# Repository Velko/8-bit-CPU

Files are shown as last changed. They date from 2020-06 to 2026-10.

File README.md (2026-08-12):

8-bit-CPU
=========

After watching [series of videos][eater-net-8bit] by Ben Eater building an 8-bit computer from scratch,
I was hooked. Various thoughts for improvements and experiments was running through my mind. But first
I have to build one. Improvements will come later. Whom am I kidding? I'll never be able to build an
exact replica, I'll incorporate improvements as I go.

In contrast to Ben, I'm not that crazy about building the whole thing on breadboards. PCBs are fine,
I like them, but building the whole thing on single board takes away the flexibility. So the plan is
to make a small board for each module and connect them together.

I plan to build a prototype module on breadboard, play around with it and then design and make a PCB
for it. It might also be interesting to make the boards little customizable (leave a chip out, create
a solder bridge, use shorter connector) so that they can be re-used for different purposes.

Of course, some parts of it might stay on a breadboard forever, or I might choose to create PCBs for
those as well. I don't know, time will tell. But the main idea is that it should be possible to swap
out PCBs for breadboards and vice versa.

Key differences from Ben's version
==================================

256 bytes of memory
-------------------

I felt that 16 bytes of total memory might be too tight, went for 8-bit addressing and 256 bytes
of memory straight from the beginning. "Real" 32 KiB SRAM chip is used, with remaining higher address
lines tied to ground. Expanding to 256 bytes does not introduce more complexity, I think that it even
made things easier. The emulated version has (and is able to use) 64KiB of memory, hardware version
has not catched up with it yet.

ROM and bootloader mode
-----------------------

I was not in the mood for _any_ DIP switch toggling for program entry, so I added an EEPROM instead.
Still I did not want to go full Harvard architecture with separate program and data memories, so
there's bootloader mode instead.

To enable it, RAM's Chip Enable is connected together with Write Enable, while ROM's Chip Enable is
connected with Output Enable of the RAM. What happens is that all reads comes from ROM and all writes
goes into RAM.

I have bootloader code in the beginning of the program that copies contents of all 256 bytes into RAM
and then patches itself (in RAM) to be skipped. It is nice to have more memory, since in original
version there are only 16 bytes total, but I can afford to _waste_ similar amount on bootloader.

In _run mode_ ROM's Chip Enable is tied to disabled state permanently, while RAM is permanently enabled.

4 flags
-------

In addition to Z and C flags, there are Negative and oVerflow flags. Took an inspiration from
[AVR Instruction Set Manual][avr-instructions], on how to implement various branching instructions.
N and V flags are required for some. N bit is just a copy of 7-th bit of the result. oVerflow indicates
that the sign bit "overflowed" as a result of addition/subtraction. In short it can be defined as:
*If sign bits of both addition operands are equal, but sign bit of the result is different, the overflow
occured.*

C flag got an additional update to act as a Borrow bit in subtraction. It behaves same way as in
Z80 / AVR / x86 processors. In subtraction the meaning of C is opposite from 6502 or Ben's version,
I find this more intuitive.

256 opcodes
-----------

As memory was expanded to 256 bytes, it was not possible to encode opcode and address in single byte
anymore. Instructions may require multiple bytes anyway now. Instruction Register loads 8-bit opcode and
extra arguments are fetched from RAM when needed, there's room for 256 opcodes.

However, number of opcodes is also limited by capacity of control EEPROMs. 8 bits for opcode + 4 bits
for flags + 3 bits for instruction step = 15 address lines. This calls for 32K EEPROM - 28C256. They
felt a little pricey when I ordered parts and I was not completely sure if I'll really need them. For
now I only have 28C64 chips, limiting number of opcodes to 64. It is still 4 times more than in Ben's
version.

There are plans to support "extended" opcodes (up to 512, or even more, if required). Planning to switch
to SST39SF010A chips for microcode ROMs. These have more capacity (and address lines) and are a bit
cheaper as well.

Modular ALU
-----------

Currently there are 2 ALU modules: Add/Subtract (with or without carry/borrow),
and AND/OR. 2 more modules are about to come - XOR/NOT, Shift/Nibble-swap.

Flags register as an independent entity
---------------------------------------

Zero flag's calculation takes input from the Bus, instead of being embedded in ALU module. This allows
to add additional ALU modules and keep just one instance of Z calculation circuitry. Additionally, it
is possible to calculate flags for anything on the Bus, for example - while loading byte from memory.
There's additional function for flags register to be sent and loaded from bus directly. Currently
there is no use for that, but it may become handy if flags need to be saved and restored for some reason
(perhaps, to implement interrupts).

Double-latching registers
-------------------------

One of the main sources of instability in Ben's design is that registers' "tap outputs" (ones that
connects registers to ALU, RAM or Control Logic) change immediately when new value is latched.
This is especially important with Flags and Instruction Register, as it creates the infamous
"EEPROM noise" on the rising clock edge, when it can cause unexpected effects. It might not be such
an issue for general-purpose registers or MAR, but it is better that everything holds steady while
the clock line is high.

The double-latching technique adds additional D flip-flops between register's primary ones and its
"tap output". These additional flip-flops are configured to latch on the inverted clock, therefore
output stays unchanged until the falling edge.

Dual-output registers
---------------------

General purpose registers got dual 3-state "tap outputs". Instead of ALU inputs being hardwired to
registers A and B, now (with appropriate control signals) it is possible to connect them differently,
for example do A + A directly. It also allows additional registers (C and D), that could be used
with ALU directly. Currently this feature is not used and control lines are wired for steady "on",
but the potential is there.

Quarter-clock
-------------

One of the sources of instability in Ben's version is RC-circuit used as an edge detector in RAM
module. A common technique is to isolate the circuit using extra logic gates, so that it does not
send spikes back in clock line. I, however, decided to eliminate the need for edge detection
completely. The thing with RAM is that it will keep loading the value all the time while Write Enable
line is enabled. If inputs change, the last value will be stored, which may not be one we want if
Write Enable is disabled on same moment as other control lines starts to change. Ben solved it using
edge detector circuit, I went in another direction and introduced a "dead time" between moment when
primary clock line goes low and inverted clock rises.

Added a counter (could have been anything that can divide the frequency) and few NOR gates on the
*clock module* I generate two 25% duty-cycle clock signals, that are offset by half of the cycle. It
looks like this:

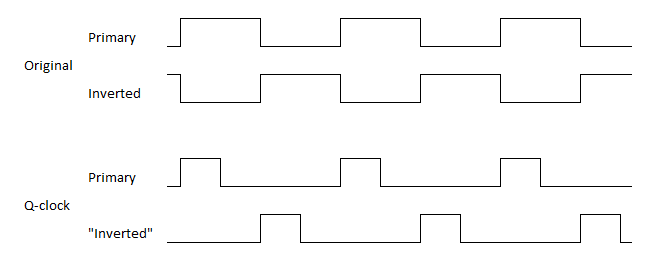
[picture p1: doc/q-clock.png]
q-clock


Part of the cycle when both clocks are low ensures that RAM's Write Enable is not active when control
lines or bus changes.

While it is required only by RAM module, I see no downsides for using it globally (it might be an issue
at high clock frequencies, though). Also, now other un-clocked parts (e.g. 193 counter for Stack Pointer)
can be introduced without worries.

Muxed control lines
-------------------

A great way to save bits in Control EEPROMs is to add demultiplexers, which activates just a single line
from several. For example, by using 74*138 demultiplexer one can expand 3 bits to 7 control lines
(technically - to 8, but you need to reserve one as "unused"). Currently there are 2 demultiplexers
used - for OUT and for LOAD lines. For OUT it also prevents "invalid" conditions, such as multiple
modules trying to output value on the bus.

While, in theory, there might be need to load same value into multiple modules simultaneously, I've
not yet encountered one, and I'm happy to live with that limitation.

No MAR, separate Address Bus
----------------------------

While trying to adjust the architecture for 16-bit memory space, I found out that having a single
Main Bus and Memory Address Register comes with performance penalty, as all address transfers takes
more cycles.

After some experimentation I found out that the most optimal solution is to remove the MAR entirely
and have a separate 16-bit Address Bus, connected directly to the RAM chip(s).

Now, for example, Progam Counter can put an address on this bus, and the data is available to be sent on the
Main Bus.

Additionally, I re-designed PC in a way, that it can output the "old" value on the Address Bus, and
increment itself simultaneously. As a result, I can reduce the fetch stage of each instruction to just
single cycle.

There are some situations (like JMP instruction), when data should be exchanged between Address and
Main buses. There's a pair of special Transfer Registers, that allows to transfer low or high bytes
between the buses.

Arduino + Python test module
----------------------------

It started with hooking up an Arduino (on its own at first, then expanded output with 595 shift registers,
expanded even more with 139 demultiplexers and finally added 165 for expanded input) and writing some
sketches to verify if modules work as expected. Soon I realized that the environment is a bit limited
and while it can prove that everything works, it is not very helpful for diagnostics.

Reducing the functions of Arduino to "set control lines", "put to bus", "read from bus", "read flags",
"pulse a clock", etc. and implementing higher level logic in Python, makes it more flexible and quicker
to develop. Wrote a "client" that uses interactive input for diagnostics.

Started to implement Python functions that acts as an assembly instructions - for example: add(A, B)
switches all control lines and issues clock ticks as needed for the addition operation. Basically -
implemented microcode in Python. Later, with refactoring it became my main microcode definition and
is used as primary source for microcode EEPROM contents.

Using the instruction-like functions and [pytest][pytest] framework wrote a quite thorough test suite.
It can check couple hundred scenarios in just few seconds and point out if something does not work as
expected. It has already saved me several times, when I did some rewiring.

At the moment the test module is swapped out for "real" EEPROM-based Control Logic, but I'll definitely
find a way to use both of them in parallel, as it is too useful to be retired.

Programmed using CustomAsm
--------------------------

There was Python-based "assembler" at first, but in the end I adopted [CustomAsm][customasm] for
machine code generation. There's an utility that takes my microcode definition and exports a file,
describing them for [CustomAsm][customasm]. It takes it from there.

Debugger & IDE
--------------
As the Test module allows great deal of flexibility, I was able to also develop a simple debugger.
It can examine registers, RAM contents, single step. Addition of BRK instruction and corresponding
control line introduced ability to set breakpoints and run the program in full-speed. Unfortunately
it only works with emulator, as current hardware doesn't support both "normal" Control Logic and
Test modules connected simultaneously.

Later I went even further and developed a simple IDE, that allows basic code editing, integrates
with [CustomAsm][customasm] for compilation and has basic debugging functionality. One can single-step,
set breakpoints, examine registers. The IDE is far from polished experience, still it is useful.

Side-projects: EEPROM and Flash writers
---------------------------------------

As side projects, there are 2 boards (Arduino Uno shields), firmware and client utility for
programming DIP-28 and PLCC-32 EEPROMs (AT28C64 and AT28C256), as well as PLCC-32 Multi-Purpose
Flash (SST39SF*).

EEPROM board has additional headers, giving access to address and data pins, allowing the board to
act as a Test module, when connected to the Main Bus and control lines.

File upload and download uses XMODEM protocol, can be used with any terminal emulator. There's also
a (*nix-only) command-line client utility for convenience.

Emulated in Verilog
-------------------

In order to be able to work with the software side of the project, when hardware was not available,
I wrote an in-Arduino emulator, that speaks same protocol as Test module. With time that proved to
be insufficient, as Arduino was still needed, so I ported the C++ code to run on PC. It worked fine,
but was a hand-crafted approximation of the CPU, so I could not really test all "what if" scenarios
I'd like to.

So I decided to build another emulator, using proper hardware description language - [Verilog][verilog].
The idea was that I first make "building blocks" - (hopefully accurate) implementations of 74-series
logic chips, and then connect them together into CPU modules. This way I get a runnable representation
of the thing, how it should be built with real chips.

To provide connectivity with (virtualized) serial port, I built additional [VPI][vpi] module.

Repository index
================

* **.github** - configuration files for GitHub integration, e.g. workflows for GitHub Actions
* **.vscode** - configuration for Visual Studio Code
* **arduino** - Arduino sketches and C++ code, to help test and automate things
    * **bouncyy** - software button debouncer and "rebouncer"
    * **pincontrol** - substitute Control Logic. Controlled via serial link from **pycontrol**
    * **xmprog** - EEPROM/Flash programmer, file upload using XMODEM protocol
* **demo** - demo programs
* **doc** - some (mostly outdated) design thoughts, BOM, etc.
* **emulator** - hardware emulator in Verilog
    * **chips** - Verilog descriptions of (mostly 74xx) chips
    * **cpu-modules** - "wired up" CPU modules
    * **tests** - test benches for chips and modules
    * **vm** - a "virtual machine". Speaks same protocol as **pincontrol**
* **hardware** - hardware schematics, boards, etc.
    * **breadboard** - Fritzig projects for some modules
    * **pcb** - KiCad schematics and boards
        * **alu_back** - backplane board for ALU and GP registers
        * **aunit** - Arithmetic Unit (ALU module for addition and subtraction)
        * **clock** - (unfinished) Clock module
        * **control** - (unfinished) Control Logic
        * **counter** - Program Counter
        * **display_back** - backend board for Output module (7-seg display)
        * **display_front** - frontend board for Output module (7-seg display)
        * **eeprom_burner** - EEPROM writer as Arduino Uno shield
        * **flags** - Flags register
        * **flash_writer** - Arduino Uno shield - writer for SST39SF0*-series Flash chips (chosen EEPROM replacement)
        * **keyboard** - (unfinished) 4x4 keyboard scanner module
        * **lunit** - Logic Unit (ALU module for AND and OR)
        * **modules** - Register, ALU, etc. boards as KiCad footprints (for backplane)
        * **ram** - (unfinished) RAM module
        * **register** - GP register
        * **sunit** - Shift Unit (ALU module for shift and nibble swap)
        * **transfer** - transfer register (between Main Bus and Address Bus)
* **include** - C and .def files for inclusion on other programs
* **misc** - miscellaneous utilities
    * **digits** - an utility to generate binary ROM image for 7-segment display
    * **xmclient** - PC-side client utility for **xmprog**
* **parts** - custom KiCad symbols and footprints for missing components
* **pycontrol** - Python-based control logic, microcode, tests, demo programs, etc.
    * **ide** - a simple PyGTK-based IDE with graphical debugger
    * **libcpu** - main implementation of control logic, microcode
    * **stubs** - MyPy type definitions for packages that lack those
    * **tests** - PyTest scripts, testing (real or emulated) hardware and PyControl itself
    * **tools** - various tools that generates microcode, customasm definitions, execute and debug binaries
* **simulation** - [Logisim][logisim] and [Digital][digital] simulations for tricky logic
* **turbo** - high-performance hardware emulator in Rust
    * **core** - core CPU implementation
    * **peripherals** - implementations of various peripherals, e.g. displays, UART, etc.
    * **bridge** - communication bridge between emulator and clients over UDP
    * **vm** - a "virtual machine", tying it all together

Progress
========

* Created Github project and added few most immediate tasks
* Wrote an introductionary README (this one ;-) )
* Decided on overall design
* Compiled list of modules and parts for first experiments, placed an order with my favorite supplier
* Found Arduino, breadboard and few 7-segment displays at home. Time to practice!
* Built breadboard prototypes for Clock, Register, Counter, Display and EEPROM burner
* Built ALU, complete with upgraded Flags register.
* Wrote some [blog posts][velkoraspi] about the "adventures"
* Arduino-based testing device. Connect the module, run a command and it verifies that module works
  as expected.
* Designed, soldered PCB versions of Register, ALU, Flags and EEPROM programmer
* Reworked testing device - moved most logic to "client" side. Coding in Python is a lot quicker
  than constantly re-flashing the Arduino. Can use unit-test framework, use debugger, quick edits.
* Beginnings of instruction set.
* Soldered 2 more Registers, to be used as MAR and IR
* Built breadboard prototype of RAM module (placed MAR and IR on it), wrote some unittests for it
* Wired both ALU and RAM blocks to Arduino, merged test suites
* Hey, it can calculate and there's memory. That should be enough to do something more complex.
* Developed Sieve of Eratosthenes - calculate prime numbers up to 256. A Python program, which uses
  assembly-like functions to manipulate the ALU and RAM modules. All variables/arrays required for
  algorithm are stored in the RAM. The control flow reads its input only from Flags register. This
  should be almost 1:1 translatable to assembly / machine code
* Play around with Python AST visitor to automatically "flatten" the program and add necessary labels
  and jumps to replace Python's while/if/continue/break control flow. When executed, this program generates
  machine code.
* Built a dedicated "debug control" board using Nano, shift registers and demultiplexers
* Connected Program Counter and "read-back" from IR into Arduino. Should be able to "run" programs from
  memory
* Developed a Python-side instruction interpreter, which uses input from IR and flags to select and
  execute appropriate microcode steps. Now it really runs machine code, albeit using weird (and very slow)
  control logic
* Developed utility that dumps current microcode (Python) definitions to C arrays.
* Wrote an Arduino-side instruction interpreter that uses the C microcode arrays and input from IR and
  Flags. Now can run programs without Python-side involvement
* Added an EEPROM in RAM module. Added a bootloader code in the Prime Sieve demo. The bootloader copies
  contents from ROM into RAM and patches itself to be skipped next time
* Implemented a "quarter clock" on the Clock board. Now it produces two 25% duty-cycle clock signals,
  instead of two 50% ones. This should eliminate need for edge-detection circuitry in RAM module.
* Built an EEPROM-based control board. Flashed microcode into ROMs.
* Swapped out Arduino-based control board with EEPROM-based one. A very error-prone operation, I must admit.
* IT'S ALIVE!!! The Sieve of Eratosthenes runs without involvement of any additional processor!
* I pushed it for speed. Initially there were some instability, but I noticed that connection of N flag
  from Flags to Control Logic was loose. Nothing in the code uses N flag for now, that's why it did not
  fail immediately. Once that was fixed, it appears to be rock-solid. I even pulled the capacitor from the
  astable clock, making it go as fast as it can. It's been running that way for over a week - not a single
  misstep.
* Some shooting, video editing and [announcement on Reddit][first-announce].
* Working on updated versions of boards, as there were design issues
* Improving reliability of Python code by adding type annotations
* Wrote emulators. Python-side instruction interpreter for quick code debugging and in-Arduino hardware
  emulator. These should help to move software side forward while there is no combined Arduino- and
  EEPROM-based control logic.
* Fixed/redesigned new versions for Arithmetic Unit and Flags boards. An experimental ALU backplane.
* Extended in-Arduino hardware emulator to 16-bit addressing. An easy way to check out various ideas
  before actually building the hardware.
* Adopted [CustomAsm][customasm] for machine code generation. Can retire my own Python-Assembly.
* Developed a debugger (breakpoints, single step, live register inspection).
* Designing additional ALU modules, miniaturized Display module.
* Ported hardware emulator to run on PC. Configured GitHub Actions to run tests.
* Designed boards for AND/OR unit, Display module, Program Counter, Transfer Register, Flash Writer
* Started re-trace branch. Software side and emulation has progressed quite far since first demo.
  On the hardware side, new boards are just starting to roll in, and I need microcode and programs
  to test the build. Can not really just follow the original version history path, because then I
  will not have access to latest software improvements. (CustomAsm, MyPy, etc.), Instead I took the
  "latest and greatest" and removed all features that are not supported by hardware yet. Will gradually
  add those back as I assemble the CPU.
* Replaced the hardware emulator with one developed in Verilog. Implemented 74-series chips as basic
  building blocks. The rest of the machine is "wired up" from those blocks. It gives a runnable version
  and represents how it can be built on breadboards or PCBs. Same as previous implementation, it can
  be controlled via virtual serial connection.
* Merged EEPROM burner, Flash writer and XMProg firmwares into one. Now it can program EEPROMs and Flash
  ROMs (should plug in the right Arduino shield) from binary file uploads over XMODEM protocol.
  Interestingly, something in Arduino library was interfering with serial communication, so everything
  was ported to C and depends on [AVR-Libc][avr-libc] only. The built-in functionality of content
  generation for 7-segment display and microcode ROMs were ported to separate utilities.
* Developed a simple IDE / GUI debugger. Probably I should've created a VSCode extension, but it I feel
  more comfortable in creating a whole app in PyGTK.
* Designing "universal" I/O controller, up to 64 (or 256) ports for external devices.
* Extracted the device pinout and instruction set definitions from Python code into separate yaml files.
  This way they can be used by an alternative implementations, for example - a high-performance emulator
  in C or Rust.
* Switched from virtual serial connection to UDP. It is more flexible and also allows to "hot-reconnect"
  with a different tool. It also appears that performance is better, especially when running in GitHub
  Actions. To use with an Arduino-based control board, I may try it using Socat or implement an
  UDP-to-Serial bridge myself, but I'll do that in due time.
* Implemented classic Snake game. It listens for input on UART and sends back ANSI-escaped output.
  Fixed a lot of issues and added new features to make it possible.
* Reimplemented the GUI debugger as TUI, using [Textual][textual] library. It is more convenient to
  run it in SSH session. No code editing nor compilation features, focused on debugger because it was
  fiddly to run the GTK version in remote session. It was quite hard to develop the Snake game demo
  without usable debugger UI. I had only a cmd-based one, which was not very convenient.
* Implemented another emulator, this time in Rust. This is a high-performance one, nicknamed "Turbo".
  It can be controlled using the same protocol as the Verilog-based emulator, so it can be used as a
  drop-in replacement. The performance difference is staggering - the Snake game does not have a chance
  to receive an input before the snake has ran into a wall. In Verilog emulator the game was playable,
  despite that it does not wait on any timers to slow down.

[eater-net-8bit]: https://eater.net/8bit
[velkoraspi]: https://velkoraspi.blogspot.com/
[avr-instructions]: http://ww1.microchip.com/downloads/en/devicedoc/atmel-0856-avr-instruction-set-manual.pdf
[pytest]: https://docs.pytest.org/en/stable/
[first-announce]: https://www.reddit.com/r/beneater/comments/loy9kj/important_milestone_it_works/
[customasm]: https://github.com/hlorenzi/customasm
[digital]: https://github.com/hneemann/Digital
[logisim]: http://www.cburch.com/logisim/
[verilog]: https://en.wikipedia.org/wiki/Verilog
[vpi]: https://en.wikipedia.org/wiki/Verilog_Procedural_Interface
[avr-libc]: https://www.nongnu.org/avr-libc/user-manual/index.html
[textual]: https://textual.textualize.io/

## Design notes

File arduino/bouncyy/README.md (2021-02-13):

Bouncyy
=======

A small tool for switch de-bounce and external debouncer testing. It takes an
input from switch, performs debouncing in software and outputs clean signal.

Also it generates another output, that is guaranteed to bounce few times.
This signal is intended to test if other (e.g. 555-based) debouncers are up
to the task. Mechanical switches are unpredictable and may or may not introduce
noticable bounces, but this tool will do.

It is implemented using "Arduino Femto" (bare ATtiny25 chip), but it should be
easily portable to larger Arduino boards.

Wiring
------

The device is a bare ATtiny25 chip, it requires only power and ground. Input
and output should be wired as follows:

* PB2 - switch input (active low, pull-up enabled)
* PB0 - debounced output (active high, debounced)
* PB1 - re-bounced output (active low, guaranteed bounce, copies button)

Programming
-----------

ATtiny should be wired to external programmer - it is required to connect MISO,
MOSI, SCK and RESET pins.

The Makefile is configured for [USBasp][usbasp] programmer, but it should be
possible to adapt it easily for other devices.

When fresh ATtiny is programmed, it is necessary to adjust its _fuse bits_, as
the default setting is to run it using internal 1 MHz clock. While it could have
been enough for this application, I prefer to switch the clock to 8 MHz mode. The
command for this is:

    make fuses

The firmware can be uploaded using command:

    make upload

[usbasp]: https://www.fischl.de/usbasp/

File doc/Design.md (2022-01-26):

Overall design
==============

The overall structure starts out same as used in breadboard computer built by Ben Eater. It has,
however, evolved quite a lot away from it.

+------------+  +------------+------------+
|     PC     |  | Register A |   Add/Sub  |
+------------+  +------------+------------+
|     LR     |  | Register B |   And/Or   |
+------------+  +------------+------------+
|     RAM    |  | Register C | Shift/Swap |
+------------+  +------------+------------+
|     TH     |  | Register D |   Xor/Not  |
+------------+  +------------+------------+
|     TL     |  |    Flags   |     ?      |
+------------+  +------------+------------+
|     SP     |
+------------+
|    ACalc   |
+------------+

+------------+
|     IR     |
+------------+

+------------+
|    OUT     |
+------------+

Each module eventually will be implemented as PCB. All modules should be plugged into a back-bone
PCB, that provides bus connectivity, power and control signals. Module PCBs should be designed in
a way that allows them to be plugged into breadboards.

Planned modules are:
* CLK          - clock
* Register A-D - general purpose registers
* Add/Sub      - ALU module for addition and subtraction
* And/Or       - ALU module for bitwise AND and OR
* Shift/Swap   - ALU module for bit shift and nibble-swap
* Xor/Not      - ALU module for bitwise XOR and negation
* Flags        - flags register
* PC           - program counter
* LR           - link (return address) register
* RAM          - memory
* TH/TL (TX)   - transfer register (between Main and Address buses)
* SP           - stack pointer
* ACalc        - address calculator (for relative addressing)
* OUT          - numeric output register
* IR           - instruction (decoder) register

* DSP   - display
* IN    - input device
* CTRL  - control unit
* BUSM  - bus monitor
* TEST  - Arduino-based test module

Registers
=========

General purpose registers A, B, C, and D should be able to load 8-bit value from the bus, output it
back and provide two 3-state "tap" outputs for connecting them to ALU argument buses.

Additional requirement here is that "tap" outputs should stay constant for the whole first part of
clock cycle, even if new value is loaded. This can be achieved by second stage of D flip-flops, that
loads data from primary stage on rising edge of inverted clock.

Minimal implementation
----------------------

All registers are built using 74HC173 register chips, and 74HC245 as output buffers.

As GP register can be re-used for another purposes (e.g. Instruction Register), PCB footprints can
be kept unpopulated, if there is no need for particular feature.

Buses
=====

In contrast to Ben's computer, this design features several buses:

* Main Bus      - 8-bit bus, connecting registers, ALU outputs, RAM data. This is equivalent to
                  "The Bus" in Ben's design;
* Address Bus   - 16-bit bus, connecting PC, SP, TX, etc. to the RAM address. It replaces Memory
                  Address Register in Ben's design, connecting RAM directly to address source without
                  wasting extra clock cycles;
* ALU arg Buses - a pair of 8-bit buses, connecting GP register "tap" outputs to Left-hand and
                  Right-hand argument inputs of ALU modules. This allows use of arbitrary GP register
                  for any argument. In Ben's design, register A was always connected to Left and B
                  to the Right argument input of ALU;
* Flags minibus - 4-bit bus, linking ALU modules to Flags register. There are Carry-In, Carry-Out,
                  oVerflow and Zero signals;

Obsolete information follows, should be actualized
====================================================================================================

Clock
=====

Clock follows the same 555-timer based design as built by Ben Eater. However, efforts were made
to reduce the chip count. In current design, only 3 chips remains on the board, but the functionality
is equivalent to the original.

Arithmetic logic unit
=====================

Arithmetic logic unit follows same basic design as built by Ben Eater. It provides just 2 operations -
addition and sutraction. ALU uses tap connections to registers A and B to obtain its operands.

Module contains additional features:
* Carry-In and Carry-Out signal handling (configurable in Z80 or 6502 modes)
* oVerflow flag calculation

The oVerflow flag is useful when performing calculations with signed values. According to
[AVR Instruction Set Manual][http://ww1.microchip.com/downloads/en/devicedoc/atmel-0856-avr-instruction-set-manual.pdf]
it is required to implement instructions like BRLT or BRGE.

More info: http://teaching.idallen.com/dat2343/10f/notes/040_overflow.txt

In short: oVerflow bit should be set if adding 2 numbers with the same sign produces a result with different
sign. Given that sign is bit7 (in case of 8-bit values), it can be calculated using the following formula:

!(a xor b) and (a xor s)

The rules are slightly different for subtraction. But same formula applies if b7 bit is taken from adder's
input, after it has been adjusted by a XOR gate.

It was decided to move Zero flag calculation from ALU to the Flags register itself. For this to work,
the result value should be put onto the Bus.

There are several additional ALU modules planned for other operations:
* AND/OR - provide 2 bitwise logic operations
* XOR/NOT - provide 2 bitwise logic operations
* SHL/SHR - shift operations

ALU modules communicate with Flags register using special "flags minibus". Transmission of Carry-Out
and Overflow flags should be controlled using tri-state buffers.

Flags register
==============

The flags register is expanded to 4 bits: Z, C, N and V:
* Zero     - result of calculation is 0. Register calculates the bit from value currently on the main
             bus;
* Carry    - loaded from the "flags minibus";
* Negative - result of calculation was negative. Register loads bit7 from the main bus;
* oVerflow - loaded from the "flags minibus";

For operations that does not affect Carry and oVerflow bits, the same value should be kept on next load.
An easy way to achieve this is connect the output of the current values back to the inputs using a
resistor.

Flags register should put current value of the Carry flag out to separate line on "flags minibus", for
ALU modules to use. To support operations where Carry flag is ignored (e.g. ADD vs ADC instructions) the
value should be ANDed with a control signal.

The register provides a tap connection to current value, to be used by Control logic.

Additional feature is to ouput current value of the flags register onto the bus and load back from
it. This will be reguired on future expansion, if interrupts are implemented. Additionally it can be
used for instructions that modifies the flags (e.g. CLC, SEC). The output should affect only 4 lines on
the bus, giving an opportunity for another module to complete the Status Register with another 4 bits
(e.g. I flag).

RAM
===

Depending on available RAM chips, it might be built either similarly to one built by Ben.
Alternatively, we could go for larger (perhaps 256 byte) module. We will not be able to use more
than 16 bytes from it at the begining, but it might be useful when we advance to improvements stage.

In any case - RAM will use tap connection to MAR register for the address. In contrast to Bens
design, we are not going to provide DIP switch-based programming mode. In earliest stages the RAM
contents will be loaded using TEST module. Later they should be entered using Input device or other
means (storage EEPROM).

Display
=======

Follows same design as build by Ben Eater. Uses tap connection into OUT register for the displayed
value. As 28C64 EEPROM is used, it provides 4 display modes (unsigned, signed, hex, oct). There's
still one unused address line, providing capacity for 4 more modes.

Additional efforts should be taken to provide sufficient display brightness, as driving 7 segment
displays directly from EEPROM / demux is not enough.

Input device
============

The final device is planned to consist from 4x4 key matrix for hexadecimal data input. It should be
designed separately as it appears to be quite complex. But it should be built using same techniques
as the Computer (no cheating with microcontrollers).

Control unit
============

The same EEPROM based microcode machine, as designed by Ben. There are, however, room for improvements.

* use 3-to-8 line decoder to provide OUT signals. Will take less bits on EEPROM, and prevents faulty
  condition, when multiple modules tries to output values on the bus
* use 6 bits from Instruction register, providing room for 64 instructions. In fact, it could be
  designed to take all 8, so that it could be expanded using larger EEPROMs;
* use 4 bits flags register, providing more opportuntities for conditions;

There are 13 address lines for 28C64 EEPROMs, they are used:
* 3 - instruction step
* 4 - flags condition
* 6 - instruction opcode

When expanded to 28C256, there are 15 address lines in total. If same design is kept, the opcode
can be expanded to full 8 bits.

There is no room for "chip select" line, which enabled Ben to write same contents to both microcode
EEPROMs. But that is just a slight inconvinience, compared to potential benefits. Also, I'm not
convinced that 2 microcode EEPROMs will be enough. To add 3rd (and 4th) one and keep the "chip select"
feature, we will need 2 address lines.

Bus monitor
===========

A simple board with LEDs, to display current status of the bus data lines.

Test module
===========

Rather than fiddling around with wires or DIP switches to test various scenarios, we can connect an
Arduino to the bus and control lines. It should also speed up loading programs into Computers
memory. Note that this will be only connected during development process. Final project will not
contain any other processors, just Computer itself.

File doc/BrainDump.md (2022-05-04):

Random thoughts
===============

Flags:
------
* Carry - available immediately
* Zero  - NORing + ANDing
* Negative - available immediately
* Overflow - XORing and stuff

C, Z, N, O flags gives us same branching opportunities as AVR architecture

Calculating O flag:
http://teaching.idallen.com/dat2343/10f/notes/040_overflow.txt

!(a xor b) and (a xor s)

(a xor s) and (b xor s)

Zero:

 s0 nor s1 | s2 nor s3 | s4 nor s5 | s6 nor s7
          and          |          and
                      and

Overflow:

 a7 xor b7 |     1     |  a7 xor s7
          xor          |
                      and

 a7 xor s7  |  b7 xor s7
           and

https://www.dcode.fr/boolean-expressions-calculator

Expanded arch:
256 instructions - 8 bits
  8 stages       - 3 bits
  4 flags        - 4 bits
---------------------------
                 15 bits  = 28C256 EEPROM
                 no room for word select

Expand further:
512 instructions - 9 bits (IR + ext.bit)
  8 stages       - 3 bits
  4 flags        - 4 bits
---------------------------
                 16 bits  = SST39SF010A
                 one extra address bit

Notes for blog
==============

* building display
    * use clock module temporarly
    * testing using Arduino
    * switch to standalone 555 and flickering
    * http://www.ohmslawcalculator.com/555-astable-calculator
    * brightening plans (darlingtons ???)
    * finding the segments/bit experimentally
    * use compiler to prepare the digit bytes
    * sprintf formatting

* Migrating to Python command interpreter
* Trying KiCad
* Issues with multiple sketches in VSCode extension - verify + upload

* U/D Counter
    * more versatile (8-bit, up / down)
    * issues with reset
    * missing edge detector
    * inverse clock also useful, could save one NOR gate
    * probably needed some NANDs as well
    * https://logic.ly/demo
    * worries about RC edge detector
    * better part, but unavail: 74x169
    * https://en.wikipedia.org/wiki/List_of_7400-series_integrated_circuits

* Order 2
    * Ran out of breadboards
    * 556, NANDs, breadboards
    * do I needed to order JK flip-flops as well?

* Keyboard
    * Rearrange the keys
    * Initial idea
    * Post on Reddit / idea about pin7
    * Latching logic
    * Pair with Display

Far future
==========

Input device / bootloader
-------------------------

Add input device to provide data / help with programming. Make the Computer execute bootloader code.

Needed features:
* in this mode instruction fetch reads from ROM instead of RAM (additional bit in microcode?)
* "unhalt" the clock
* read from I/O device into A
* store A into address pointed by B
* add immediate to B
* (optional) load conents from address pointed by B into A

What about creating an input device that scans 4x4 array of buttons. Use ready-made 4x4 keypad
matrix. May need to re-label it for hex digit input.

Clock + 4-bit counter, 2-to-4 decoder, 4 ANDs, Quad-OR can detect key-press. 2x 4-bit registers, to
latch in the value. Evaluate if it is possible to move current values from A to B while loading new
into A. Also need a way to get single clock pulse when key detected (wasn't there something in the
Bens videos???).

RAM signals
===========

RAM:

* ~OE~
* ~WE~

Buffer:

* ~OE~  - ~BOE~
* DIR

DIR HIGH -> A2B (up)
    LOW  -> B2A (down)

do nothing (display current):
   ~OE~ = LOW
   ~WE~ = HIGH
   ~BOE~ = HIGH
   DIR  = dont care

read from RAM:
   ~OE~ = LOW
   ~WE~ = HIGH
   ~BOE~ = LOW
    DIR = HIGH

write to RAM:
    ~OE~ = HIGH
    ~WE~ = LOW  (clocked)
    ~BOE~ = LOW
    DIR = LOW

for easier wiring - flip the buffer around, so the ~OE~ and DIR are same
can connect them together then

Control signals for RAM

RAM Out: active low
RAM Load: active low

internal - ~OE~ == DIR

Clock: 25%

Truth table:

OUT | LOAD | CLOCK | Function | BOE | OE | WE
-----------------------------------------------
 H  |  H   |   L   | Nothing  |  H  | L  | H
 H  |  H   |   H   | Nothing  |  H  | L  | H
 L  |  H   |   L   | Out      |  L  | L  | H
 L  |  H   |   H   | Out      |  L  | L  | H
 H  |  L   |   L   | Load     |  L  | H  | H
 H  |  L   |   H   | Load     |  L  | H  | L
 L  |  L   |   x   | invalid  |  *  | *  | *

WE = !(CLOCK AND !LOAD)
OE = !LOAD
BOE = OUT AND LOAD

OE = not(LOAD)
WE = CLOCK nand not(LOAD)
BOE = not(OUT nand LOAD)

OE = not(LOAD)
WE = CLOCK nand OE
BOE = not(OUT nand LOAD)

Clocking 25% duty
=================

        +---+   +---+   +---+   +---+   +---+   +---+
SRC     |   |   |   |   |   |   |   |   |   |   |   |
      __|   |___|   |___|   |___|   |___|   |___|   |___

         +-------+       +-------+       +-------+
/2+D     |       |       |       |       |       |
      ___|       |_______|       |_______|       |______

         +--+   ++       +--+   ++       +--+   ++
AND      |  |   ||       |  |   ||       |  |   ||
      ___|  |___||_______|  |___||______ |  |___||______

       +------------+  +------------+  +------------+
OR     |            |  |            |  |            |
     __|            |__|            |__|            |__

     --+            +--+            +--+            +--
NOR    |            |  |            |  |            |
       |____________|  |____________|  |____________|

Diagrams
========

https://app.diagrams.net/

Some links
==========
https://alternatezone.com/electronics/files/PCBDesignTutorialRevA.pdf
https://designingelectronics.com/

PCB order batches
=================

v1.0
----
    * Register 1.0
    * Add/Sub 1.0
    * Flags 1.0
    * EEPROM burner 1.0

v1.1
----
    * Flags 2.1
    * Add/Sub 1.2
    * ALU backplane 1.0

v1.2
----
    * And/Or 1.0
    * Display Backend 1.0
    * Display Frontend 1.0
    * Transfer Register 1.0
    * Program Counter 1.0
    * Flash Writer 1.0

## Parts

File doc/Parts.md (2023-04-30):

Component list
==============

Register
--------

* 2 x 74HC173 - 4-bit register
* 1 x 74HC245 - output buffer
* 8 x LEDs
* 8 x 1kΩ resistors
* 1 x 16-pin IDC header
* 2 x  6-pin IDC header
* 2 x 0.1 μF capacitor
* 1 x 2-pin 1-row socket

Program Counter
---------------

* 2 x 74HC161 - 4-bit counter (or 74HC191 for future features)
* 1 x 74HC245 - output buffer
* 8 x LEDs
* 8 x 1kΩ resistors
* 1 x 16-pin IDC header
* 2 x  6-pin IDC header
* 2 x 0.1 μF capacitor
* 1 x 2-pin 1-row socket

Clock
-----

* 2 x LM555 - timer
* 1 x 1M potentiometer
* 1 x button
* 1 x 74HC08 - AND gate
* 1 x 74HC32 - OR gate
* 1 x 74HC04 - inverter
* 1 x 1μF capacitor
* 3 x 0.1 μF capacitor
* 1 x 0.01 μF capacitor
* 1 x microUSB socket
* 1 x 16-pin IDC header
* 1 x 2-position switch
* 1 x LED
* 4 x 1kΩ resistor
* 1 x 1MΩ resistor
* 2 x 10kΩ resistor
* 1 x 74HC02 - NOR gate

Display
-------

* 1 x LM555 -timer
* 4 x 7-segment displays (common cathode)
* 1 x 74HC161 - counter (alternative: 74HC163)
* 1 x 74HC138 - demux (or 74HC139)
* 1 x AT28C64 - EEPROM
* 1 x MCR7H4H-16RA - rotary encoded switch
* 2 x 0.01μF capacitor
* 2 x 0.1μF capacitor
* 8 x 1kΩ resistor

EEPROM programmer
-----------------

* 2 x 74HC594 shift registers

Keyboard
--------

* 1 x 4x4 keyboard matrix
* 1 x 74HC161 - counter (or 74HC163)
* 2 x 74HC138 demux (or 1 x 74HC139)
* 2 x 74HC173 - output latches
* 1 x 74HC245 - output buffer
* 4 x 10kΩ resistor
* 2 x 74HC02 - NOR gate
* 1 x 74HC08 - AND gate
* 1 x LM555 -timer

... uncertain about the rest, should play around with it first

ALU
---

* 1 x 74HC245 - output buffer
* 2 x 74HC283 - 4-bit adder
* 2 x 74HC86 - Quad XOR gate
* 1 x 4HC02 - NOR gate
* 1 x 74HC08 - AND gate
* 1 x 74HC173 - 4-bit register
* 10 x LEDs
* 10 x 1kΩ resistor
* 1 x 16-pin IDC header
* 4 x  6-pin IDC header

RAM
---

* 1 x 71256SA20TPG - 32kB RAM module (DIP). Is an overkill but there is no smaller available
* 1 x 16-pin IDC header
* 4 x  6-pin IDC header

... uncertain about the rest, should play around with it first

Bus monitor
-----------

* 8 x LED
* 8 x 1kΩ resistor
* 1 x 16-pin IDC header

Control unit
------------

* 1 x 74HC161 - counter (74HC163 might suit even better)
* 2 x AT28C64 - EEPROM
* 2 x 74HC138 - demux
* 8 x LED
* 16 x LED
* 24 x 1kΩ resistor

Builds
======

Stage 1
-------

The plan is to build a breadboard module for some modules, probably reusing the parts for another,
more complex build, after the module is tested.

* clock
* register
* program counter
* ALU

Only "main" components should be ordered. No need for connectors, headers, etc.

Logic chips:
* 5 x 74HC173 - 4-bit register
* 4 x 74HC245 - output buffer
* 5 x 74HC161 - 4-bit counter
* 3 x 74HC08 - AND gate
* 1 x 74HC32 - OR gate
* 1 x 74HC04 - inverter
* 4 x 74HC02 - NOR gate
* 5 x 74HC138 - demux
* 2 x 74HC594 shift registers
* 2 x 74HC283 - 4-bit adder
* 2 x 74HC86 - Quad XOR gate

Other chips:
* 3 x AT28C64 - EEPROM
* 1 x 71256SA20TPG - 32kB RAM module (DIP).
* 4 x LM555 - timer

Mechanical:
* 1 x 4x4 keyboard matrix
* 1 x MCR7H4H-16RA - rotary encoded switch
* 1 x 1M potentiometer
* 1 x button
* 1 x 2-position switch

Optical:
* 4 x 7-segment displays (common cathode) (already have at home)
* bunch of LEDs (various colors)

Extra materials:
* some DIP switches (4 and 8 pole)
* breadboards

I couldn't source 74HC161 at the moment. Will try to use 74HC163 instead.
Also, there's 74HC191. That will give us a nice Up/Down counting capability
(and is a bit cheaper as well).

Grabbed 74HC139 as well - will save some space on board for keyboard build.

74HC161 and 74HC163 differs only on reset functionality (former is async,
latter - sync). For some places it doesn't matter, as I'm not going to reset
it anyway. In Control Logic, it might be even better to have it synchronous.

Additional "fun"
----------------

* EEPROM programmer
* Display
* Keyboard
* RAM

Stage 2
=======

PCBs will be designed and build for most commonly used modules.

Main:
* clock
* register (will need a lot)
* program counter
* ALU
* Flags reg

Additionally:
* bus monitor
* EEPROM burner

Parts for PCBs
--------------

SMD LEDs
SMD capacitors: 10nF, 100nF, 1uF
SMD resistors: 1K, 10K, 1M, 330

Additional parts
----------------
* MIC2981 - source driver
* LED bars
* resistor networks
* Buffers DIP version of those in ALU
* MUX

Side projects
=============
* 1.8432MHz oscillator (try to build UART)
* MC21605H6WK-FPTLW-V2 - LCD screen
* Arduino Nano
* 74HC40105 - FIFOs for UART (Farnell only lists NXP, not produced, there are TI elsewhere)

PCB Order 1
===========

PCBs were designed for EEPROM writer, Arithmetic unit, Register and Flags. Following is the BOM for
each unit. As General Purpose register will be used for Instruction and Memory Address registers,
there should be enough parts to build 4.

EEPROM programmer
-----------------

* 4x disc cap 5mm, 100nF
* 1x 0805 cap 100nF
* 4x PinSocket 1x8
* 2x PinHeader 1x8
* 1x PinHeader 1x6
* 1x PinHeader 1x10
* 1x resistor 10K
* 2x 74HC595 (or 74HC595)
* 1x DIP-28-W socket
* 1x PLCC-32 socket

Arithmetic unit
---------------
* 4x 0805 cap 100nF
* 1x 0805 cap 10μF
* 8x 0805 LED yellow
* 3x 0805 LED green
* 2x 0805 LED red
* 3x PinHeader 1x8
* 2x PinHeader 1x4
* 1x PinHeader 2x2
* 13x 0805 resistor 1K (or 330)
* 2x 0805 resistor 10K
* 2x 74HC283 SOIC-16W_5.3x10.2mm_P1.27mm
* 3x 74HC86 SOIC-14_3.9x8.7mm_P1.27mm
* 1x 74HC08 SOIC-14_3.9x8.7mm_P1.27mm
* 1x 74HC245 SO-20_12.8x7.5mm_P1.27mm
* 1x 74HC125 SOIC-14_3.9x8.7mm_P1.27mm

Register
--------
* 7x 0805 cap 100nF
* 1x 0805 cap 10μF
* 8x 0805 LED yellow
* 4x 0805 LED red
* 3x PinHeader 1x8
* 2x PinHeader 1x4
* 1x PinHeader 2x2
* 12x 0805 resistor 1K (or 330)
* 4x 0805 resistor 10K
* 1x 0805 resistor 100K
* 3x 74HC245 SO-20_12.8x7.5mm_P1.27mm
* 4x 74HC173 SOIC-16_3.9x9.9mm_P1.27mm

Flags
-----
* 6x 0805 cap 100nF
* 1x 0805 cap 10μF
* 4x 0805 LED green
* 4x 0805 LED red
* 1x PinHeader 1x8
* 4x PinHeader 1x4
* 1x PinHeader 2x2
* 8x 0805 resistor 1K (or 330)
* 6x 0805 resistor 10K
* 1x 0805 resistor 100K
* 1x 74HC02 SOIC-14_3.9x8.7mm_P1.27mm
* 1x 74HC08 SOIC-14_3.9x8.7mm_P1.27mm
* 1x 74HC157 SOIC-16_3.9x9.9mm_P1.27mm
* 2x 74HC173 SOIC-16_3.9x9.9mm_P1.27mm
* 1x 74HC125 SOIC-14_3.9x8.7mm_P1.27mm

Total
-----
* 39x 0805 cap 100nF
* 6x 0805 cap 10μF
* 7x 0805 LED green
* 40x 0805 LED yellow
* 22x 0805 LED red
* 5x 0805 resistor 100K
* 24x 0805 resistor 10K
* 69x 0805 resistor 1K (or 330)
* 1x 74HC02 SOIC-14_3.9x8.7mm_P1.27mm
* 2x 74HC08 SOIC-14_3.9x8.7mm_P1.27mm
* 2x 74HC125 SOIC-14_3.9x8.7mm_P1.27mm
* 1x 74HC157 SOIC-16_3.9x9.9mm_P1.27mm
* 18x 74HC173 SOIC-16_3.9x9.9mm_P1.27mm
* 13x 74HC245 SO-20_12.8x7.5mm_P1.27mm
* 2x 74HC283 SOIC-16W_5.3x10.2mm_P1.27mm
* 2x 74HC595 (or 74HC595)
* 3x 74HC86 SOIC-14_3.9x8.7mm_P1.27mm
* 1x DIP-28-W socket
* 4x disc cap 5mm, 100nF - on stock @ home
* 1x PLCC-32 socket
* 1x PinHeader 1x10 - will improvise
* 14x PinHeader 1x4
* 1x PinHeader 1x6 - will improvise
* 18x PinHeader 1x8
* 6x PinHeader 2x2
* 4x PinSocket 1x8
* 1x resistor 10K - on stock @ home

Additional
----------
74HC125 DIP
74HC157 DIP - not on stock
MIC2981
ULN2003
LED bars
resistor networks 1K x 10
MC21605H6WK-FPTLW-V2 - LCD screen
Arduino Nano

Next order
==========

74HC74  - dual D flip-flop with complementary out - for q-clock
More breadboards
74HC193 - up/down counters
74HC595 SOIC (what is in stock)
SST39SF010A - flash (can be slower ones)
More PLLC-32 sockets
RAM SMD - 256 Kbit, 32K x 8bit
2x2 & 4x1 females
SC52-11SRWA/SC52-11EWA - brighter displays (whichever is in stock)
Or smaller - 4 digit one
More yellow Leds, register, buffers
MC14490 - bounce eliminator?

Output module PCB+
=================

* TLC555 timer SOIC
* 100 ohm resistors 0805
*  50 ohm resistors (in case 100 is still too large)
* 10nF capacitors 0805
* SC39-11GWA displays

RAM:
===
https://eu.mouser.com/c/?q=61C1024

Extras
======

47590-0001 Micro USB

613020243121 - right angle receptacle

61301021021 - right angle header

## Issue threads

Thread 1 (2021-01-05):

EEPROM burner - component overlap

Velko, 2021-01-05:
A chip and decoupling capacitor overlaps with Arduino USB connector. Can not insert board completely. It works but some insulation layer is needed.

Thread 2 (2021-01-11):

Flags register - decoupling capacitor

Velko, 2021-01-11:
The decoupling capacitor of U3 (74HC157) is located at wrong end of the chip, far away from VCC pin

Velko, 2021-05-20:
Fixed, new version of board.

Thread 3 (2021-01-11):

Flags register - wrong footprint

Velko, 2021-01-11:
The footprint of U3 (74HC157) is wrong. The footprint used on board is SOIC-16W_5.3x10.2mm. It is possible to solder the chip, but it should have been narrower.

Velko, 2021-01-11:
Same goes for U4 and U5 - both 74HC173

Velko, 2021-01-13:
... and also Adder chips in ALU

Closed 2021-05-20.

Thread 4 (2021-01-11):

EEPROM burner - decoupling capacitor in inconvenient place

Velko, 2021-01-11:
Decoupling capacitor for DIP EEPROM makes it a bit inconvenient to remove the chip from socket.

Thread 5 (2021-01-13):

Flags register - unconnected pin

Velko, 2021-01-13:
Pin 10 of the output latch chip is not connected. In schematic it is connected to GND, but was not routed in PCB.

Luckily, neighboring pin 9 is connected (to GND), so the workaround is to put an intentional solder bridge between these pins.

Closed 2021-05-20.

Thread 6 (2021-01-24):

Flags register - improvements

Velko, 2021-01-24:
Additional good to have:

- change the level of SEL signal to opposite. Load from bus when low, calculate from bus when high. Should be easier when wiring up with the rest of the logic
- use_carry pass-thru mode. Add a jumper, that passes the control signal directly to flags bus. It may be more flexible to control the behavior from Control Word directly.

Velko, 2021-02-11:
Even better idea: change the meaning of the input signals to "load from bus" and "calc from bus" (both active low). Should be possible to use the onboard AND gate, currently used for "use carry" function. This will make carry pass-thru mode permanent.

Closed 2021-05-20.

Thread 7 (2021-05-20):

ALU backpane: miswired ALU input selectors

Velko, 2021-05-20:
B2 address line controls A input selector, along with B forced zero. Should control B inputs instead.

Was able to bodge-fix:
- A0-1 and B0-1 are swapped
- B2 reassigned to different pin
- forced zero works on B=6

Velko, 2025-03-14:
As I do not intend to continue to use this board for other purposes than a demonstration, hardwired the ALU inputs to A as LHS argument and B as RHS.

The ALU argument input connector now has only single input for the ALT function (3rd pin from the top).

Closed 2025-03-14.

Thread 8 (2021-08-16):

Transfer register: Swapped LOAD controls

Velko, 2021-08-16:
ALOAD control signal actually loads from Main Bus, while MLOAD from Address Bus.

ADDR LED shows signals as intended.

Board is functional, when swapping LOAD connections to Control Logic to compensate, but LED shows wrong source.

Appears to be an easy re-route on PCB. Bodge is probably not worth it.

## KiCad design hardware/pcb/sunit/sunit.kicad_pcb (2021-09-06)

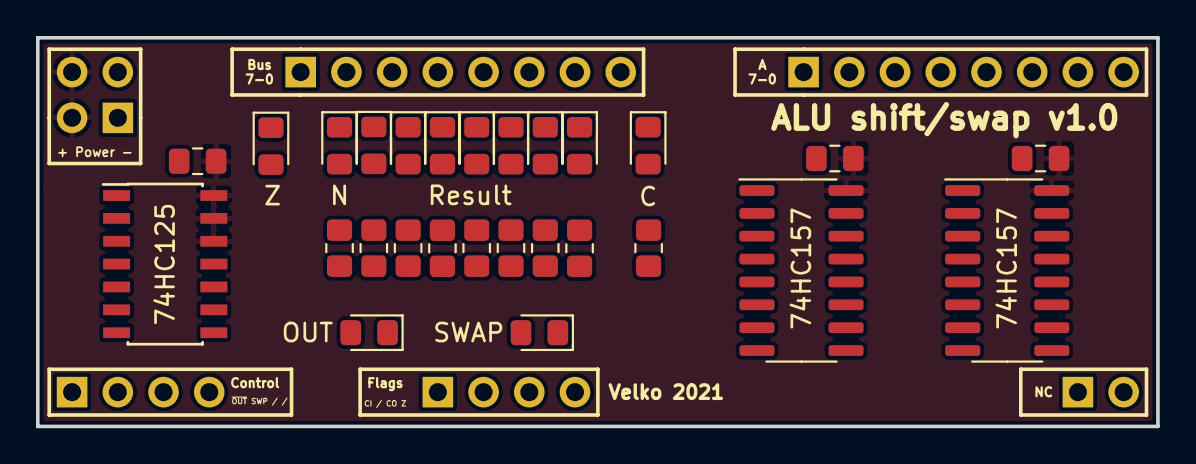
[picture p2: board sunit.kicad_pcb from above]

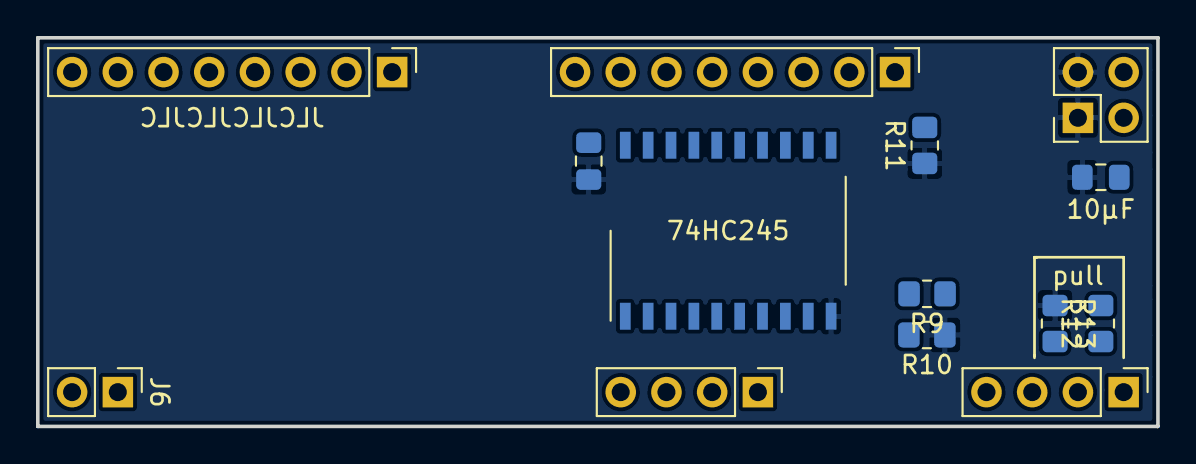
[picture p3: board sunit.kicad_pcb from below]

Board: 4 copper layers, 62.2 x 21.6 mm, 41 parts (14 on the bottom side), 45 nets, no tracks yet.

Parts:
C1: 10μF; C_0805_2012Metric_Pad1.15x1.40mm_HandSolder
C2, C3, C6, C8: 100nF; C_0805_2012Metric_Pad1.15x1.40mm_HandSolder
D1: 0; LED_0805_2012Metric_Pad1.15x1.40mm_HandSolder
D2: 1; LED_0805_2012Metric_Pad1.15x1.40mm_HandSolder
D3: 2; LED_0805_2012Metric_Pad1.15x1.40mm_HandSolder
D4: Result; LED_0805_2012Metric_Pad1.15x1.40mm_HandSolder
D5: 4; LED_0805_2012Metric_Pad1.15x1.40mm_HandSolder
D6: 5; LED_0805_2012Metric_Pad1.15x1.40mm_HandSolder
D7: 6; LED_0805_2012Metric_Pad1.15x1.40mm_HandSolder
D8: N; LED_0805_2012Metric_Pad1.15x1.40mm_HandSolder
D9: OUT; LED_0805_2012Metric_Pad1.15x1.40mm_HandSolder
D10: SWAP; LED_0805_2012Metric_Pad1.15x1.40mm_HandSolder
D11: Z; LED_0805_2012Metric_Pad1.15x1.40mm_HandSolder
D12: C; LED_0805_2012Metric_Pad1.15x1.40mm_HandSolder
J1: Power; PinHeader_2x02_P2.54mm_Vertical
J2: Control; PinHeader_1x04_P2.54mm_Vertical
J3: BUS; PinHeader_1x08_P2.54mm_Vertical
J4: Input A; PinHeader_1x08_P2.54mm_Vertical
J5: Flags; PinHeader_1x04_P2.54mm_Vertical
J6: Input B; PinHeader_1x02_P2.54mm_Vertical
R1, R2, R3, R4, R5, R6, R7, R8, R9, R10, R11, R14: 330; R_0805_2012Metric_Pad1.20x1.40mm_HandSolder
R12, R13: 10K; R_0805_2012Metric_Pad1.20x1.40mm_HandSolder
U5: 74HC125; SOIC-14_3.9x8.7mm_P1.27mm
U6, U7: 74HC157; SOIC-16_3.9x9.9mm_P1.27mm
U8: 74HC245; SO-20_12.8x7.5mm_P1.27mm

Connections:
A0: J4.8, U5.2, U5.5, U6.3
A1: J4.7, U6.6, U7.2
A2: J4.6, U6.10, U7.5
A3: J4.5, U6.13, U7.11
A4: J4.4, U7.3, U7.14
A5: J4.3, U6.2, U7.6
A6: J4.2, U6.5, U7.10
A7: J4.1, U6.11, U7.13
BUS0: J3.8, U8.18
BUS1: J3.7, U8.17
BUS2: J3.6, U8.16
BUS3: J3.5, U8.15
BUS4: J3.4, U8.14
BUS5: J3.3, U8.13
BUS6: J3.2, U8.12
BUS7: J3.1, U8.11
CIN: J5.1, U6.14
COUT: J5.3, U5.6
GND: C1.2, C2.2, C3.2, C6.2, C8.2, D1.1, D2.1, D3.1, D4.1, D5.1, D6.1, D7.1, D8.1, J1.1, J1.2, R10.1, R11.1, R13.1, R14.1, U5.1, U5.7, U6.8, U6.15, U7.8, U7.15, U8.10
unnamed: D1.2, R1.1
unnamed: D2.2, R2.1
unnamed: D3.2, R3.1
unnamed: D4.2, R4.1
unnamed: D5.2, R5.1
unnamed: D6.2, R6.1
unnamed: D7.2, R7.1
unnamed: D8.2, R8.1
unnamed: D9.2, R9.2
unnamed: D10.1, R10.2
unnamed: D11.1, R11.2
unnamed: D11.2, U5.8
unnamed: D12.1, R14.2
unnamed: D12.2, U5.3
RES0: R1.2, U7.4, U8.2
RES1: R2.2, U7.7, U8.3
RES2: R3.2, U7.9, U8.4
RES3: R4.2, U7.12, U8.5
RES4: R5.2, U6.4, U8.6
RES5: R6.2, U6.7, U8.7
RES6: R7.2, U6.9, U8.8
RES7: R8.2, U6.12, U8.9
SH_SWP: D10.2, J2.2, R13.2, U6.1, U7.1
VCC: C1.1, C2.1, C3.1, C6.1, C8.1, J1.3, J1.4, R9.1, R12.2, U5.12, U5.13, U5.14, U6.16, U7.16, U8.1, U8.20
ZIN: J5.4, U5.9
~OUT~: D9.1, J2.1, R12.1, U5.4, U5.10, U8.19

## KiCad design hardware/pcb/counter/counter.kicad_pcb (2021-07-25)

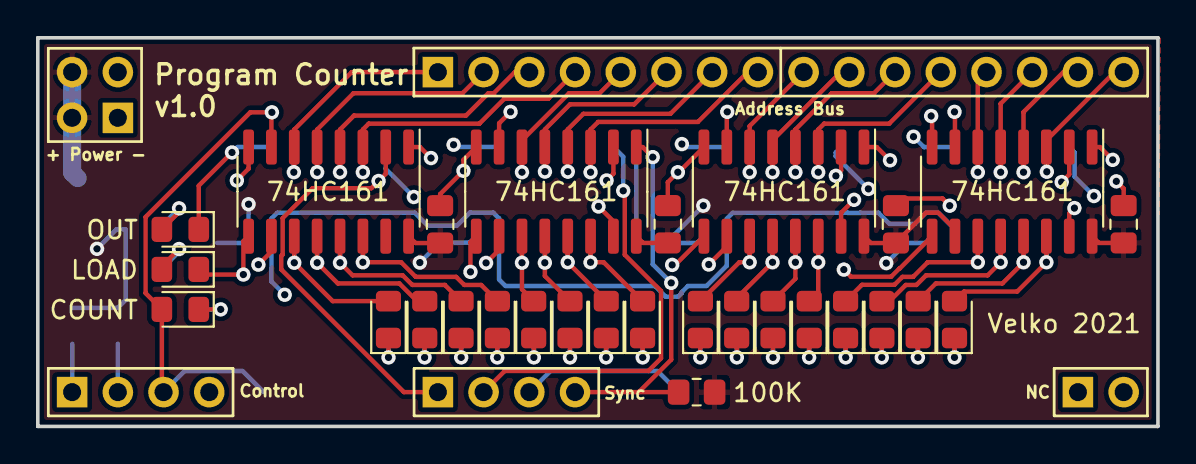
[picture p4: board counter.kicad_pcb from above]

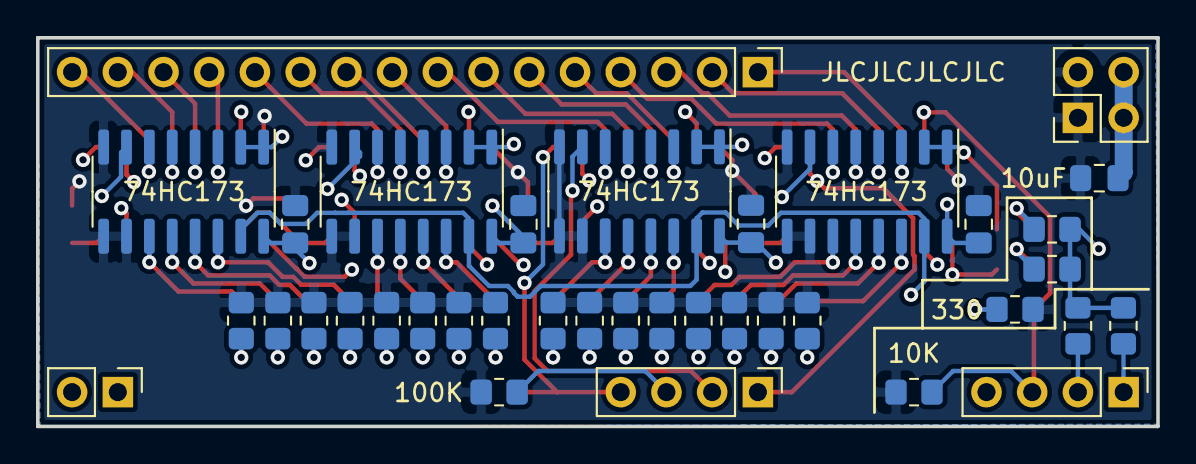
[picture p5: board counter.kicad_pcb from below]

Board: 4 copper layers, 62.2 x 21.6 mm, 65 parts (37 on the bottom side), 63 nets.

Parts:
C1, C2, C3, C4, C5, C6, C7, C8: 100nF; C_0805_2012Metric_Pad1.18x1.45mm_HandSolder
C9: 10uF; C_0805_2012Metric_Pad1.18x1.45mm_HandSolder
D1, D2, D3, D4, D5, D6, D7, D8, D9, D10, D11, D12, D13, D14, D15, D16: LED; LED_0805_2012Metric_Pad1.15x1.40mm_HandSolder
D17: OUT; LED_0805_2012Metric_Pad1.15x1.40mm_HandSolder
D18: LOAD; LED_0805_2012Metric_Pad1.15x1.40mm_HandSolder
D19: COUNT; LED_0805_2012Metric_Pad1.15x1.40mm_HandSolder
J2: Control; PinHeader_1x04_P2.54mm_Vertical
J3: Sync; PinHeader_1x04_P2.54mm_Vertical
J4: + Power -; PinHeader_2x02_P2.54mm_Vertical
J5: Address Bus; PinHeader_1x16_P2.54mm_Vertical
J6: NC; PinHeader_1x02_P2.54mm_Vertical
R1, R2, R3, R4, R5, R6, R7, R8, R9, R10, R11, R12, R13, R14, R15, R16, R17, R19, R21: 330; R_0805_2012Metric_Pad1.20x1.40mm_HandSolder
R18, R20, R22: 10K; R_0805_2012Metric_Pad1.20x1.40mm_HandSolder
R23, R24: 100K; R_0805_2012Metric_Pad1.20x1.40mm_HandSolder
U1, U5, U7, U9: 74HC161; SOIC-16_3.9x9.9mm_P1.27mm
U2, U6, U8, U10: 74HC173; SOIC-16_3.9x9.9mm_P1.27mm

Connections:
ABUS0: J5.16, U1.3, U2.6
ABUS1: J5.15, U1.4, U2.5
ABUS2: J5.14, U1.5, U2.4
ABUS3: J5.13, U1.6, U2.3
ABUS4: J5.12, U5.3, U6.6
ABUS5: J5.11, U5.4, U6.5
ABUS6: J5.10, U5.5, U6.4
ABUS7: J5.9, U5.6, U6.3
ABUS8: J5.8, U7.3, U8.6
ABUS9: J5.7, U7.4, U8.5
ABUS10: J5.6, U7.5, U8.4
ABUS11: J5.5, U7.6, U8.3
ABUS12: J5.4, U9.3, U10.6
ABUS13: J5.3, U9.4, U10.5
ABUS14: J5.2, U9.5, U10.4
ABUS15: J5.1, U9.6, U10.3
AOUT: D17.1, J2.1, R18.1, U2.1, U2.2, U6.1, U6.2, U8.1, U8.2, U10.1, U10.2
CLK: J3.1, U1.2, U5.2, U7.2, U9.2
GND: C1.2, C2.2, C3.2, C4.2, C5.2, C6.2, C7.2, C8.2, C9.2, J4.1, J4.2, R1.1, R2.1, R3.1, R4.1, R5.1, R6.1, R7.1, R8.1, R9.1, R10.1, R11.1, R12.1, R13.1, R14.1, R15.1, R16.1, R21.1, R22.2, R24.1, U1.8, U2.8, U2.9, U2.10, U5.8, U6.8, U6.9, U6.10, U7.8, U8.8, U8.9, U8.10, U9.8, U10.8, U10.9, U10.10
ICLK: J3.2, U2.7, U6.7, U8.7, U10.7
LOAD: D18.1, J2.2, R20.1, U1.9, U5.9, U7.9, U9.9
unnamed: D1.1, R1.2
unnamed: D2.1, R2.2
unnamed: D3.1, R3.2
unnamed: D4.1, R4.2
unnamed: D5.1, R5.2
unnamed: D6.1, R6.2
unnamed: D7.1, R7.2
unnamed: D8.1, R8.2
unnamed: D9.1, R9.2
unnamed: D10.1, R10.2
unnamed: D11.1, R11.2
unnamed: D12.1, R12.2
unnamed: D13.1, R13.2
unnamed: D14.1, R14.2
unnamed: D15.1, R15.2
unnamed: D16.1, R16.2
unnamed: D17.2, R17.2
unnamed: D18.2, R19.2
unnamed: D19.1, R21.2
unnamed: U1.15, U5.10
unnamed: U5.15, U7.10
unnamed: U7.15, U9.10
Q0: D1.2, U1.14, U2.11
Q1: D2.2, U1.13, U2.12
Q2: D3.2, U1.12, U2.13
Q3: D4.2, U1.11, U2.14
Q4: D5.2, U5.14, U6.11
Q5: D6.2, U5.13, U6.12
Q6: D7.2, U5.12, U6.13
Q7: D8.2, U5.11, U6.14
Q8: D9.2, U7.14, U8.11
Q9: D10.2, U7.13, U8.12
Q10: D11.2, U7.12, U8.13
Q11: D12.2, U7.11, U8.14
Q12: D13.2, U9.14, U10.11
Q13: D14.2, U9.13, U10.12
Q14: D15.2, U9.12, U10.13
Q15: D16.2, U9.11, U10.14
RST: J3.3, R24.2, U2.15, U6.15, U8.15, U10.15
UP: D19.2, J2.3, R22.1, U1.7, U5.7, U7.7, U9.7
VCC: C1.1, C2.1, C3.1, C4.1, C5.1, C6.1, C7.1, C8.1, C9.1, J4.3, J4.4, R17.1, R18.2, R19.1, R20.2, R23.1, U1.10, U1.16, U2.16, U5.16, U6.16, U7.16, U8.16, U9.16, U10.16
~RST~: J3.4, R23.2, U1.1, U5.1, U7.1, U9.1

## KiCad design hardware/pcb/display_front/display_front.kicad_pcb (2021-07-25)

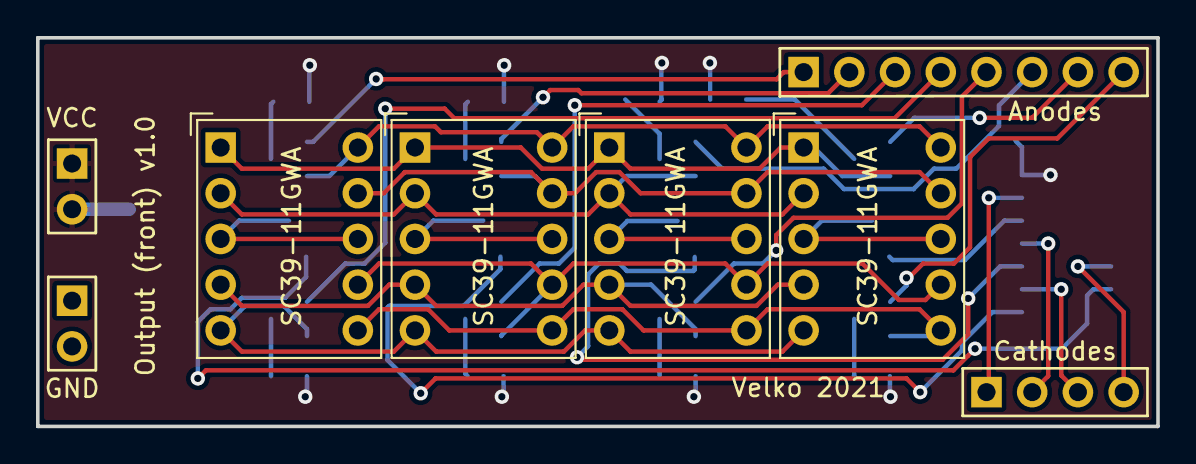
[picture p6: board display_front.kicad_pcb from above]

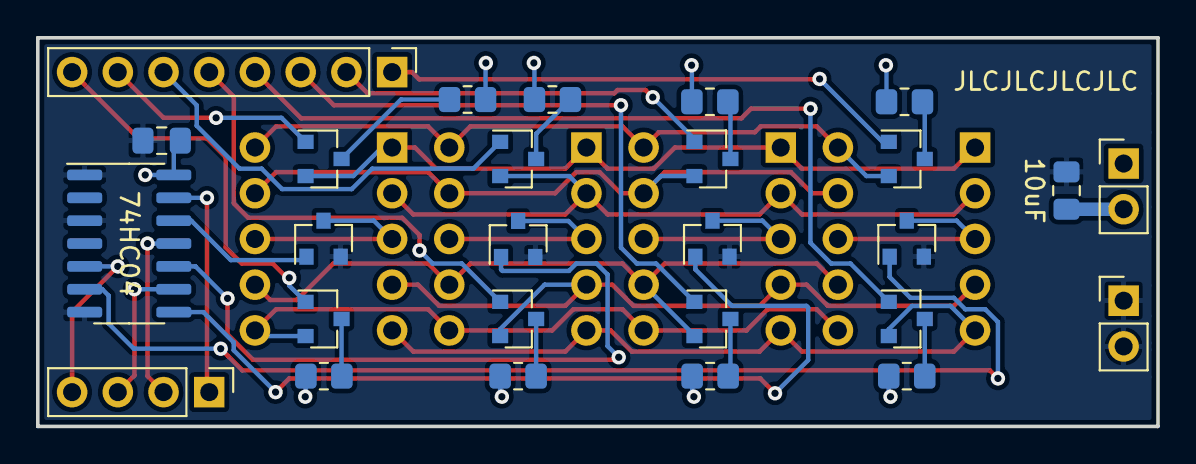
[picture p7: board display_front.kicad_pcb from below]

Board: 2 copper layers, 62.2 x 21.6 mm, 31 parts (27 on the bottom side), 38 nets.

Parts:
C9: 100nF; C_0805_2012Metric_Pad1.18x1.45mm_HandSolder
C10: 10uF; C_0805_2012Metric_Pad1.18x1.45mm_HandSolder
J5: Anodes; PinHeader_1x08_P2.54mm_Vertical
J6: Cathodes; PinHeader_1x04_P2.54mm_Vertical
J9: VCC; PinHeader_1x02_P2.54mm_Vertical
J10: GND; PinHeader_1x02_P2.54mm_Vertical
Q1, Q2, Q3, Q4, Q5, Q6, Q7, Q8, Q9, Q10, Q11, Q12: Q_NMOS_GSD; SOT-23
R1, R2, R3, R4, R5, R6, R7, R8: 100; R_0805_2012Metric_Pad1.20x1.40mm_HandSolder
U1: 74HC04; SOIC-14_3.9x8.7mm_P1.27mm
U2, U3, U4, U5: SC39-11GWA; Sx39-1xxxxx

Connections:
A: Q2.2, U2.10, U3.10, U4.10, U5.10
B: Q5.2, U2.9, U3.9, U4.9, U5.9
C: Q4.2, U2.7, U3.7, U4.7, U5.7
CA0: J6.1, U1.13
CA1: J6.2, U1.11
CA2: J6.3, U1.9
CA3: J6.4, U1.5
D: Q3.2, U2.5, U3.5, U4.5, U5.5
DA: J5.1, Q2.1
DB: J5.2, Q5.1
DC: J5.3, Q4.1
DD: J5.4, Q3.1
DDP: J5.8, Q12.1
DE: J5.5, Q7.1
DF: J5.6, Q9.1
DG: J5.7, Q10.1
DP: Q12.2, U2.6, U3.6, U4.6, U5.6
E: Q7.2, U2.4, U3.4, U4.4, U5.4
F: Q9.2, U2.2, U3.2, U4.2, U5.2
G: Q10.2, U2.1, U3.1, U4.1, U5.1
GND: C9.2, C10.2, J10.1, J10.2, Q1.2, Q6.2, Q8.2, Q11.2, U1.1, U1.3, U1.7
unnamed: Q1.1, U1.6
unnamed: Q1.3, U2.3, U2.8
unnamed: Q2.3, R1.2
unnamed: Q3.3, R4.2
unnamed: Q4.3, R3.2
unnamed: Q5.3, R2.2
unnamed: Q6.1, U1.8
unnamed: Q6.3, U3.3, U3.8
unnamed: Q7.3, R5.2
unnamed: Q8.1, U1.10
unnamed: Q8.3, U4.3, U4.8
unnamed: Q9.3, R6.2
unnamed: Q10.3, R7.2
unnamed: Q11.1, U1.12
unnamed: Q11.3, U5.3, U5.8
unnamed: Q12.3, R8.2
VCC: C9.1, C10.1, J9.1, J9.2, R1.1, R2.1, R3.1, R4.1, R5.1, R6.1, R7.1, R8.1, U1.14

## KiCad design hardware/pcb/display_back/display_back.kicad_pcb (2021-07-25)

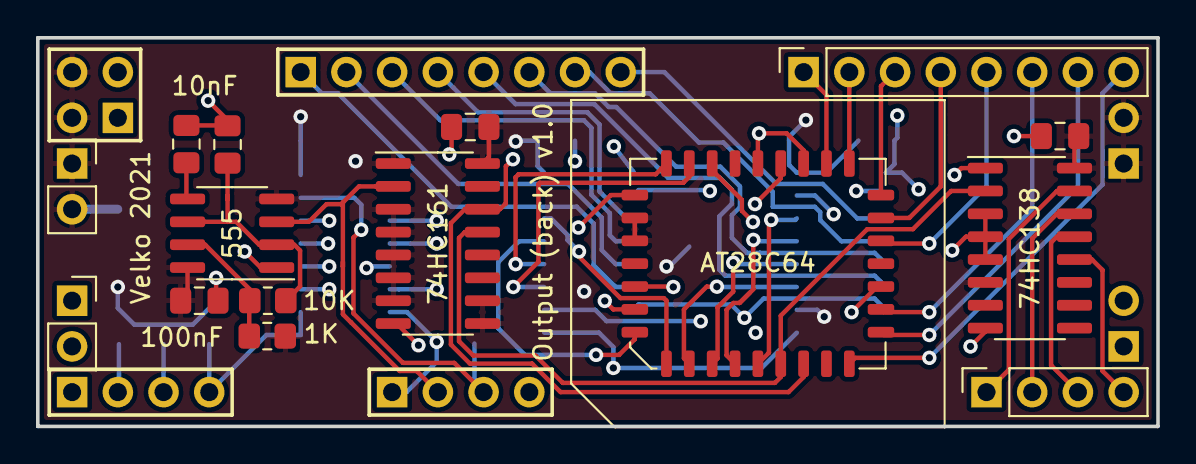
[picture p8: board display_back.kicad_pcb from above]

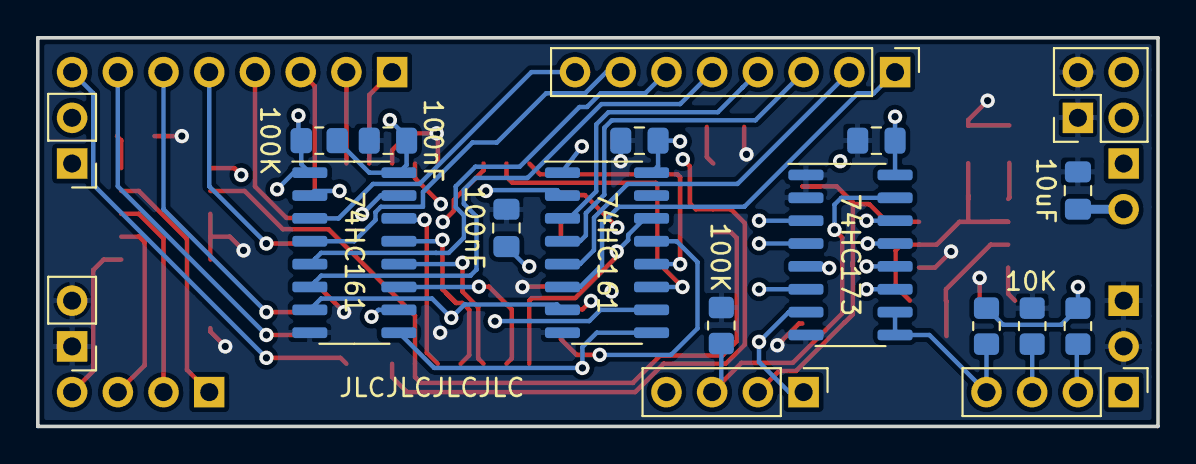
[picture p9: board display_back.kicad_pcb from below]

Board: 4 copper layers, 62.2 x 21.6 mm, 34 parts (19 on the bottom side), 47 nets.

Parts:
C1, C2: 10nF; C_0805_2012Metric_Pad1.18x1.45mm_HandSolder
C3, C4, C5, C6, C7, C8, C9: 100nF; C_0805_2012Metric_Pad1.18x1.45mm_HandSolder
C10: 10uF; C_0805_2012Metric_Pad1.18x1.45mm_HandSolder
J1: Conn_01x08_Male; PinHeader_1x08_P2.54mm_Vertical
J2, J3: Conn_01x04_Male; PinHeader_1x04_P2.54mm_Vertical
J4: Conn_01x04_Male; PinHeader_2x02_P2.54mm_Vertical
J5: DISP_ANODES; PinSocket_1x08_P2.54mm_Vertical
J6: DISP_CATHODES; PinSocket_1x04_P2.54mm_Vertical
J7: AUX_VCC; PinHeader_1x02_P2.54mm_Vertical
J8: AUX_GND; PinHeader_1x02_P2.54mm_Vertical
J9: VCC_OUT; PinSocket_1x02_P2.54mm_Vertical
J10: GND_OUT; PinSocket_1x02_P2.54mm_Vertical
R1: 1K; R_0805_2012Metric_Pad1.20x1.40mm_HandSolder
R2, R3, R4, R6: 10K; R_0805_2012Metric_Pad1.20x1.40mm_HandSolder
R5, R7: 100K; R_0805_2012Metric_Pad1.20x1.40mm_HandSolder
U1: AT28C64; PLCC-32_SMD-Socket
U2, U3, U4: 74HC161; SOIC-16_3.9x9.9mm_P1.27mm
U5: 74HC138; SOIC-16_3.9x9.9mm_P1.27mm
U6: 74HC173; SOIC-16_3.9x9.9mm_P1.27mm
U7: 555; SOIC-8_3.9x4.9mm_P1.27mm

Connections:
/CA0: J6.1, U5.15
/CA1: J6.2, U5.14
/CA2: J6.3, U5.13
/CA3: J6.4, U5.12
/DA0: J5.8, U1.13
/DA1: J5.7, U1.14
/DA2: J5.6, U1.15
/DA3: J5.5, U1.18
/DA4: J5.4, U1.19
/DA5: J5.3, U1.20
/DA6: J5.2, U1.21
/DA7: J5.1, U1.22
/M0: U1.24, U6.3
/M1: U1.27, U6.4
/M2: U1.3, U6.5
/M3: U1.30, U6.6
/MP_A0: U1.11, U2.14, U5.1
/MP_A1: U1.10, U2.13, U5.2
/V_A0: U1.9, U3.14
/V_A1: U1.8, U3.13
/V_A2: U1.7, U3.12
/V_A3: U1.6, U3.11
/V_A4: U1.5, U4.14
/V_A5: U1.4, U4.13
/V_A6: U1.29, U4.12
/V_A7: U1.28, U4.11
BUS0: J1.8, U3.3, U6.14
BUS1: J1.7, U3.4, U6.13
BUS2: J1.6, U3.5, U6.12
BUS3: J1.5, U3.6, U6.11
BUS4: J1.4, U4.3
BUS5: J1.3, U4.4
BUS6: J1.2, U4.5
BUS7: J1.1, U4.6
CLK: J3.1, U3.2, U4.2, U6.7
CLK_O: J3.2, U2.2, U7.3
COUNT: J2.3, R6.1, U3.7, U4.7
GND: C1.2, C2.2, C3.2, C4.2, C5.2, C6.2, C7.2, C8.2, C9.2, C10.2, J4.1, J4.2, J8.1, J8.2, J10.1, J10.2, R6.2, R7.2, U1.2, U1.16, U1.23, U1.25, U2.8, U3.8, U4.8, U5.3, U5.4, U5.5, U5.8, U6.1, U6.2, U6.8, U7.1
unnamed: C1.1, U7.5
unnamed: C2.1, R2.2, U7.2, U7.6
unnamed: R1.2, R2.1, U7.7
unnamed: U3.15, U4.10
RESET: J3.3, R7.1, U6.15
VCC: C3.1, C4.1, C5.1, C6.1, C7.1, C8.1, C9.1, C10.1, J4.3, J4.4, J7.1, J7.2, J9.1, J9.2, R1.1, R3.2, R4.2, R5.2, U1.31, U1.32, U2.1, U2.3, U2.4, U2.5, U2.6, U2.7, U2.9, U2.10, U2.16, U3.10, U3.16, U4.16, U5.6, U5.16, U6.16, U7.4, U7.8
~LOAD_M~: J2.4, R4.1, U6.9, U6.10
~LOAD~: J2.2, R3.1, U3.9, U4.9
~RESET~: J3.4, R5.1, U3.1, U4.1

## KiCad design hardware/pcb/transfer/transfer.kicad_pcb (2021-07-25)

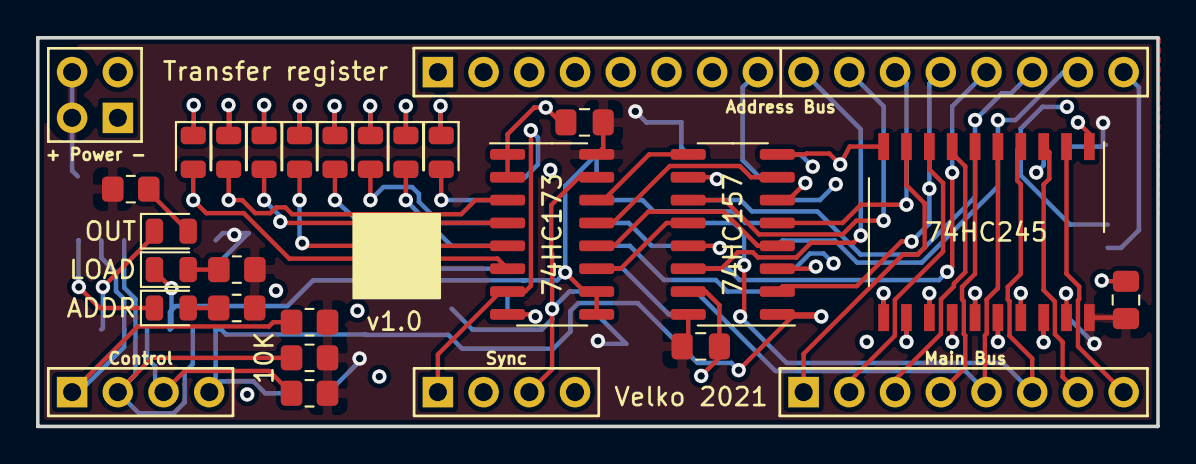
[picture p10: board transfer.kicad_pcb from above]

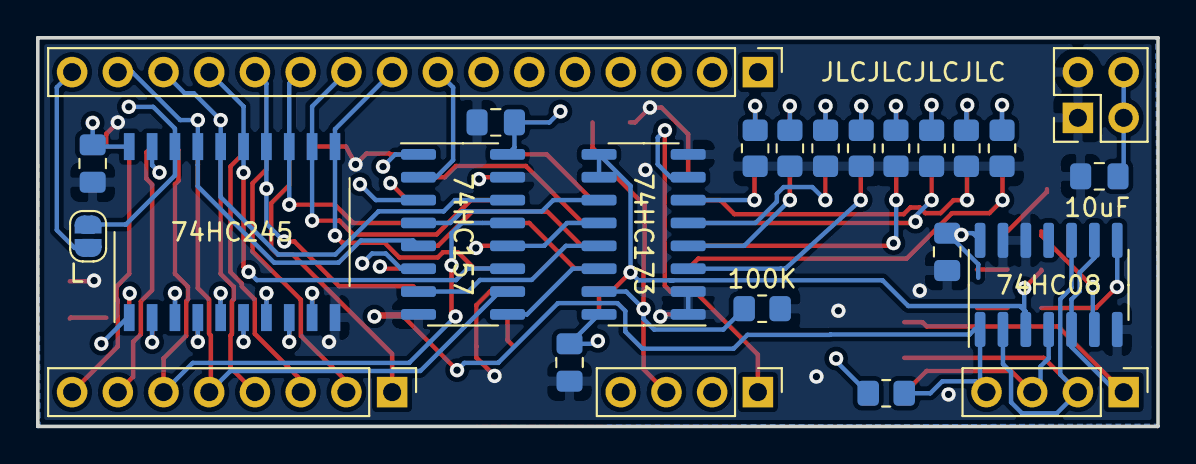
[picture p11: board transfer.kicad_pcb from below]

Board: 4 copper layers, 62.2 x 21.6 mm, 48 parts (25 on the bottom side), 55 nets.

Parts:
C1, C2, C3, C4, C5, C6, C8: 100nF; C_0805_2012Metric_Pad1.18x1.45mm_HandSolder
C7: 10uF; C_0805_2012Metric_Pad1.18x1.45mm_HandSolder
D1, D2, D3, D4, D5, D6, D7, D8: LED; LED_0805_2012Metric
D9: LOAD; LED_0805_2012Metric
D10: OUT; LED_0805_2012Metric
D11: ADDR; LED_0805_2012Metric
J2: Control; PinHeader_1x04_P2.54mm_Vertical
J3: Sync; PinHeader_1x04_P2.54mm_Vertical
J4: + Power -; PinHeader_2x02_P2.54mm_Vertical
J5: Address Bus; PinHeader_1x16_P2.54mm_Vertical
J6: Main Bus; PinHeader_1x08_P2.54mm_Vertical
JP1: L; SolderJumper-2_P1.3mm_Open_RoundedPad1.0x1.5mm
R1, R2, R3, R4, R5, R6, R7, R8, R9, R10, R11: 330; R_0805_2012Metric_Pad1.20x1.40mm_HandSolder
R12, R13, R14, R15: 10K; R_0805_2012Metric_Pad1.20x1.40mm_HandSolder
R16: 100K; R_0805_2012Metric_Pad1.20x1.40mm_HandSolder
U1, U4: 74HC173; SOIC-16_3.9x9.9mm_P1.27mm
U2, U5: 74HC157; SOIC-16_3.9x9.9mm_P1.27mm
U3, U9: 74HC245; SO-20_12.8x7.5mm_P1.27mm
U6: 74HC08; SOIC-14_3.9x8.7mm_P1.27mm

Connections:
ABUS0: J5.8, JP1.1, U2.2, U3.18
ABUS1: J5.7, J5.15, U2.5, U3.17
ABUS2: J5.6, J5.14, U2.14, U3.16
ABUS3: J5.5, J5.13, U2.11, U3.15
ABUS4: J5.4, J5.12, U3.14, U5.2
ABUS5: J5.3, J5.11, U3.13, U5.5
ABUS6: J5.2, J5.10, U3.12, U5.11
ABUS7: J5.1, J5.9, U3.11, U5.14
ALOAD: J2.2, R13.2, U6.2, U6.10
AOUT: J2.1, R12.2, U3.19, U6.5, U6.9
CLK: J3.1, U1.7, U4.7
GND: C1.2, C2.2, C3.2, C4.2, C5.2, C6.2, C7.2, C8.2, J4.1, J4.2, R1.1, R2.1, R3.1, R4.1, R5.1, R6.1, R7.1, R8.1, R16.1, U1.1, U1.2, U1.8, U2.8, U2.15, U3.10, U4.1, U4.2, U4.8, U5.8, U5.15, U6.7, U6.12, U6.13, U9.1, U9.10
LD0: U1.11, U2.4
LD1: U1.13, U2.7
LD2: U1.12, U2.12
LD3: U1.14, U2.9
LD4: U4.12, U5.4
LD5: U4.13, U5.7
LD6: U4.14, U5.9
LD7: U4.11, U5.12
LOAD: D9.1, U1.9, U1.10, U4.9, U4.10, U6.3
MBUS0: J6.8, U2.3, U9.2
MBUS1: J6.7, U2.6, U9.3
MBUS2: J6.6, U2.13, U9.4
MBUS3: J6.5, U2.10, U9.5
MBUS4: J6.4, U5.3, U9.6
MBUS5: J6.3, U5.6, U9.7
MBUS6: J6.2, U5.10, U9.8
MBUS7: J6.1, U5.13, U9.9
MLOAD: J2.4, R15.2, U2.1, U5.1, U6.1
MOUT: J2.3, R14.2, U6.4, U9.19
unnamed: D1.1, R1.2
unnamed: D2.1, R2.2
unnamed: D3.1, R3.2
unnamed: D4.1, R4.2
unnamed: D5.1, R5.2
unnamed: D6.1, R6.2
unnamed: D7.1, R7.2
unnamed: D8.1, R8.2
unnamed: D9.2, R9.2
unnamed: D10.2, R10.2
unnamed: D11.1, U6.8
unnamed: D11.2, R11.2
unnamed: J5.16, JP1.2
OUT: D10.1, U6.6
OUT0: D1.2, U1.6, U3.2, U9.18
OUT1: D2.2, U1.4, U3.3, U9.17
OUT2: D3.2, U1.5, U3.4, U9.16
OUT3: D4.2, U1.3, U3.5, U9.15
OUT4: D5.2, U3.6, U4.5, U9.14
OUT5: D6.2, U3.7, U4.4, U9.13
OUT6: D7.2, U3.8, U4.3, U9.12
OUT7: D8.2, U3.9, U4.6, U9.11
RST: J3.3, R16.2, U1.15, U4.15
VCC: C1.1, C2.1, C3.1, C4.1, C5.1, C6.1, C7.1, C8.1, J4.3, J4.4, R9.1, R10.1, R11.1, R12.1, R13.1, R14.1, R15.1, U1.16, U2.16, U3.1, U3.20, U4.16, U5.16, U6.14, U9.20

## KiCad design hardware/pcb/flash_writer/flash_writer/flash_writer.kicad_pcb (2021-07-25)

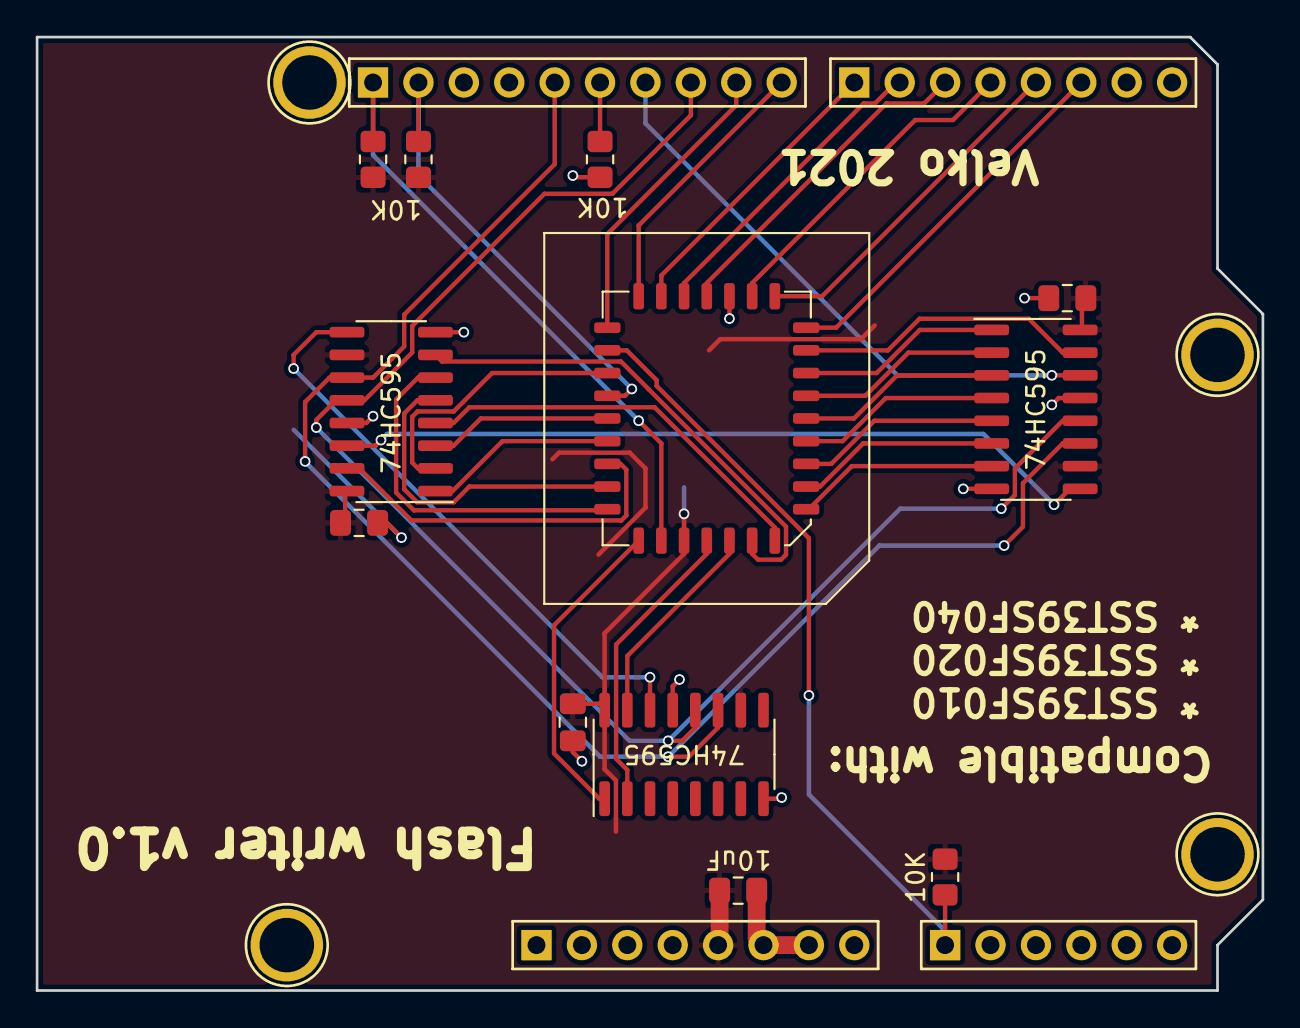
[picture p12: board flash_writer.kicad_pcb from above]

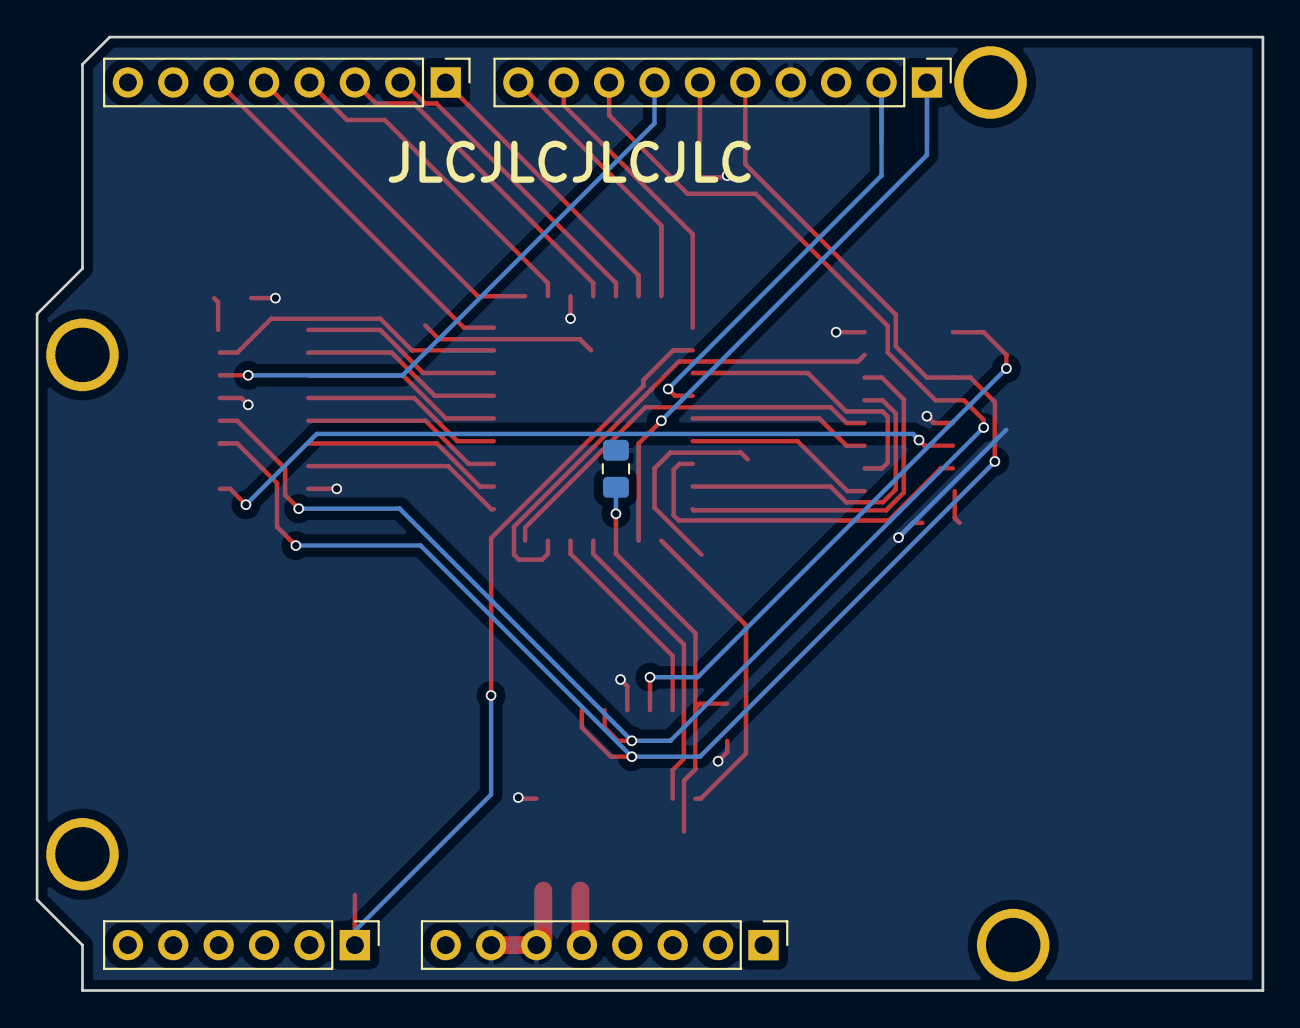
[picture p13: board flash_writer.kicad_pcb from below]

Board: 2 copper layers, 68.6 x 53.3 mm, 21 parts (5 on the bottom side), 38 nets.

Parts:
C1, C2, C3, C4: 100nF; C_0805_2012Metric_Pad1.18x1.45mm_HandSolder
C5: 10uF; C_0805_2012Metric_Pad1.18x1.45mm_HandSolder
P1: Power; PinHeader_1x08_P2.54mm_Vertical
P2: Analog; PinHeader_1x06_P2.54mm_Vertical
P3: Digital; PinHeader_1x10_P2.54mm_Vertical
P4: Digital; PinHeader_1x08_P2.54mm_Vertical
P5, P6, P7, P8: CONN_01X01; Arduino_1pin
R1, R2, R3, R4: 10K; R_0805_2012Metric_Pad1.20x1.40mm_HandSolder
U1, U2, U4: 74HC595; SOIC-16_3.9x9.9mm_P1.27mm
U3: SST39SF040; PLCC-32_SMD-Socket

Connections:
+5V: C1.1, C2.1, C3.1, C4.1, C5.1, P1.5, R1.1, R2.1, R4.1, U1.10, U1.16, U2.10, U2.16, U3.32, U4.10, U4.16
A0: U1.15, U3.12
A1: U1.1, U3.11
A2: U1.2, U3.10
A3: U1.3, U3.9
A4: U1.4, U3.8
A5: U1.5, U3.7
A6: U1.6, U3.6
A7: U1.7, U3.5
A8: U2.15, U3.27
A9: U2.1, U3.26
A10: U2.2, U3.23
A11: U2.3, U3.25
A12: U2.4, U3.4
A13: U2.5, U3.28
A14: U2.6, U3.29
A15: U2.7, U3.3
A16: U3.2, U4.15
A17: U3.30, U4.1
A18: U3.1, U4.2
D0: P4.6, U3.13
D1: P4.5, U3.14
D2: P4.4, U3.15
D3: P4.3, U3.17
D4: P4.2, U3.18
D5: P4.1, U3.19
D6: P3.10, U3.20
D7: P3.9, U3.21
GND: C1.2, C2.2, C3.2, C4.2, C5.2, P1.6, P1.7, P3.4, R3.2, U1.8, U1.13, U2.8, U2.13, U3.16, U4.8, U4.13
LATCH: P3.8, U1.12, U2.12, U4.12
MISO: P3.6, R3.1
MOSI: P3.7, U1.14
unnamed: U1.9, U2.14
unnamed: U2.9, U4.14
SCK: P3.5, U1.11, U2.11, U4.11
~CE~: P2.1, R4.2, U3.22
~OE~: P3.2, R1.2, U3.24
~WE~: P3.1, R2.2, U3.31

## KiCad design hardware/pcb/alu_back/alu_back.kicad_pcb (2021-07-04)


Board: 2 copper layers, 132.1 x 114.3 mm, 31 parts (0 on the bottom side), 73 nets.

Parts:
C1: 10uF; C_0805_2012Metric_Pad1.18x1.45mm_HandSolder
C2, C3, C4, C5: 100nF; C_0805_2012Metric_Pad1.18x1.45mm_HandSolder
H1, H2, H3, H4, H5: MountingHole; MountingHole_3mm
J1: SYNC; PinSocket_1x04_P2.54mm_Vertical
J2: BUS; PinSocket_1x08_P2.54mm_Vertical
J3: FLAGS; PinSocket_1x04_P2.54mm_Vertical
J4: OUT; PinSocket_1x08_P2.54mm_Vertical
J5: FCTL; PinSocket_1x04_P2.54mm_Vertical
J6: LOAD; PinSocket_1x04_P2.54mm_Vertical
J7: ARGS; PinSocket_1x08_P2.54mm_Vertical
J8: POWER; PinSocket_2x02_P2.54mm_Vertical
U1: Register A; Register_board
U2: Register B; Register_board
U3: Register C; Register_board
U4: Register D; Register_board
U5: Add/Sub; Register_board
U6: And/Or; Register_board
U7: Xor/Not; Register_board
U8: Shift/Swap; Register_board
U9: Flags; Flags_board
U10: 74HC125; SOIC-14_3.9x8.7mm_P1.27mm
U11: 74HC245; SO-20_12.8x7.5mm_P1.27mm
U12, U13: 74HC138; SOIC-16_3.9x9.9mm_P1.27mm

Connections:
/A0: U1.17, U2.17, U3.17, U4.17, U5.17, U6.17, U7.17, U8.17
/A1: U1.18, U2.18, U3.18, U4.18, U5.18, U6.18, U7.18, U8.18
/A2: U1.19, U2.19, U3.19, U4.19, U5.19, U6.19, U7.19, U8.19
/A3: U1.20, U2.20, U3.20, U4.20, U5.20, U6.20, U7.20, U8.20
/A4: U1.21, U2.21, U3.21, U4.21, U5.21, U6.21, U7.21, U8.21
/A5: U1.22, U2.22, U3.22, U4.22, U5.22, U6.22, U7.22, U8.22
/A6: U1.23, U2.23, U3.23, U4.23, U5.23, U6.23, U7.23, U8.23
/A7: U1.24, U2.24, U3.24, U4.24, U5.24, U6.24, U7.24, U8.24
/B0: U1.16, U2.16, U3.16, U4.16, U5.16, U6.16, U7.16, U8.16, U11.11
/B1: U1.15, U2.15, U3.15, U4.15, U5.15, U6.15, U7.15, U8.15, U11.12
/B2: U1.14, U2.14, U3.14, U4.14, U5.14, U6.14, U7.14, U8.14, U11.13
/B3: U1.13, U2.13, U3.13, U4.13, U5.13, U6.13, U7.13, U8.13, U11.14
/B4: U1.12, U2.12, U3.12, U4.12, U5.12, U6.12, U7.12, U8.12, U11.15
/B5: U1.11, U2.11, U3.11, U4.11, U5.11, U6.11, U7.11, U8.11, U11.16
/B6: U1.10, U2.10, U3.10, U4.10, U5.10, U6.10, U7.10, U8.10, U11.17
/B7: U1.9, U2.9, U3.9, U4.9, U5.9, U6.9, U7.9, U8.9, U11.18
/BUS0: J2.8, U1.25, U2.25, U3.25, U4.25, U5.25, U6.25, U7.25, U8.25, U9.17
/BUS1: J2.7, U1.26, U2.26, U3.26, U4.26, U5.26, U6.26, U7.26, U8.26, U9.18
/BUS2: J2.6, U1.27, U2.27, U3.27, U4.27, U5.27, U6.27, U7.27, U8.27, U9.19
/BUS3: J2.5, U1.28, U2.28, U3.28, U4.28, U5.28, U6.28, U7.28, U8.28, U9.20
/BUS4: J2.4, U1.29, U2.29, U3.29, U4.29, U5.29, U6.29, U7.29, U8.29, U9.21
/BUS5: J2.3, U1.30, U2.30, U3.30, U4.30, U5.30, U6.30, U7.30, U8.30, U9.22
/BUS6: J2.2, U1.31, U2.31, U3.31, U4.31, U5.31, U6.31, U7.31, U8.31, U9.23
/BUS7: J2.1, U1.32, U2.32, U3.32, U4.32, U5.32, U6.32, U7.32, U8.32, U9.24
/CAF: U5.7, U6.7, U7.7, U8.7, U9.14
/CFA: U5.5, U6.5, U7.5, U8.5, U9.16
/V: U5.6, U6.6, U7.6, U8.6, U9.15
/Z: U5.8, U6.8, U7.8, U8.8, U9.13
ALT: J7.3, U10.2, U10.5, U10.9, U10.12
ALT_AO: U6.2, U10.11
ALT_AS: U5.2, U10.8
ALT_S: U8.2, U10.6
ALT_XN: U7.2, U10.3
ARG_AL: U1.3, U13.15
ARG_AR: U1.4, U12.15
ARG_BL: U2.3, U13.14
ARG_BR: U2.4, U12.14
ARG_CL: U3.3, U13.13
ARG_CR: U3.4, U12.13
ARG_DL: U4.3, U13.12
ARG_DR: U4.4, U12.12
ARG_L0: J7.8, U13.1
ARG_L1: J7.7, U13.2
ARG_R0: J7.6, U12.1
ARG_R1: J7.5, U12.2
ARG_R2: J7.4, U12.3
ARG_ZR: U11.19, U12.9
CLK: J1.4, U1.5, U2.5, U3.5, U4.5, U9.5
GND: C1.2, C2.2, C3.2, C4.2, C5.2, J8.3, J8.4, U1.33, U1.35, U2.33, U2.35, U3.33, U3.35, U4.33, U4.35, U5.33, U5.35, U6.33, U6.35, U7.33, U7.35, U8.33, U8.35, U9.25, U9.27, U10.1, U10.4, U10.7, U10.10, U10.13, U11.2, U11.3, U11.4, U11.5, U11.6, U11.7, U11.8, U11.9, U11.10, U12.4, U12.5, U12.8, U13.3, U13.4, U13.5, U13.8
LOAD_A: J6.1, U1.2
LOAD_B: J6.2, U2.2
LOAD_C: J6.3, U3.2
LOAD_D: J6.4, U4.2
unnamed: J3.1, U9.9
unnamed: J3.2, U9.10
unnamed: J3.3, U9.11
unnamed: J3.4, U9.12
unnamed: J5.1, U9.1
unnamed: J5.2, U9.2
unnamed: J5.3, U9.3
unnamed: J5.4, U9.4
OUT_A: J4.1, U1.1
OUT_AO: J4.6, U6.1
OUT_AS: J4.5, U5.1
OUT_B: J4.2, U2.1
OUT_C: J4.3, U3.1
OUT_D: J4.4, U4.1
OUT_S: J4.7, U8.1
OUT_XN: J4.8, U7.1
RESET: J1.2, U1.7, U2.7, U3.7, U4.7, U9.7
VCC: C1.1, C2.1, C3.1, C4.1, C5.1, J8.1, J8.2, U1.34, U1.36, U2.34, U2.36, U3.34, U3.36, U4.34, U4.36, U5.34, U5.36, U6.34, U6.36, U7.34, U7.36, U8.34, U8.36, U9.26, U9.28, U10.14, U11.1, U11.20, U12.6, U12.16, U13.6, U13.16
~CLK~: J1.3, U1.6, U2.6, U3.6, U4.6, U9.6
~RESET~: J1.1, U1.8, U2.8, U3.8, U4.8, U9.8

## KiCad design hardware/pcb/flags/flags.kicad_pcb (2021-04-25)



Board: 4 copper layers, 62.2 x 21.6 mm, 42 parts (28 on the bottom side), 47 nets.

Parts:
C1, C2, C3, C4, C5, C6: 100nF; C_0805_2012Metric_Pad1.15x1.40mm_HandSolder
C7: 10μF; C_0805_2012Metric_Pad1.15x1.40mm_HandSolder
D1: Z; LED_0805_2012Metric_Pad1.15x1.40mm_HandSolder
D2: V; LED_0805_2012Metric_Pad1.15x1.40mm_HandSolder
D3: N; LED_0805_2012Metric_Pad1.15x1.40mm_HandSolder
D4: C; LED_0805_2012Metric_Pad1.15x1.40mm_HandSolder
D5: LOAD; LED_0805_2012Metric_Pad1.15x1.40mm_HandSolder
D6: BOUT; LED_0805_2012Metric_Pad1.15x1.40mm_HandSolder
D7: CALC; LED_0805_2012Metric_Pad1.15x1.40mm_HandSolder
D8: CARRY; LED_0805_2012Metric_Pad1.15x1.40mm_HandSolder
J1: Bus; PinHeader_1x08_P2.54mm_Vertical
J2: Control; PinHeader_1x04_P2.54mm_Vertical
J3: Sync; PinHeader_1x04_P2.54mm_Vertical
J4: Power; PinHeader_2x02_P2.54mm_Vertical
J5: Flags_Bus; PinHeader_1x04_P2.54mm_Vertical
J6: Ctrl_Out; PinHeader_1x04_P2.54mm_Vertical
R1, R2, R11, R12, R13, R14: 10K; R_0805_2012Metric_Pad1.15x1.40mm_HandSolder
R3, R4, R5, R6, R7, R8, R9, R10: 330; R_0805_2012Metric_Pad1.15x1.40mm_HandSolder
R15: 100K; R_0805_2012Metric_Pad1.15x1.40mm_HandSolder
U1: 74HC02; SOIC-14_3.9x8.7mm_P1.27mm
U2: 74HC08; SOIC-14_3.9x8.7mm_P1.27mm
U3: 74HC157; SOIC-16_3.9x9.9mm_P1.27mm
U4, U5: 74HC173; SOIC-16_3.9x9.9mm_P1.27mm
U6: 74HC125; SOIC-14_3.9x8.7mm_P1.27mm

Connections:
BUS0: J1.8, U1.8, U3.11, U6.8
BUS1: J1.7, U1.9, U3.14, U6.11
BUS2: J1.6, U1.6, U3.5, U6.3
BUS3: J1.5, U1.5, U3.2, U6.6
BUS4: J1.4, U1.11
BUS5: J1.3, U1.3
BUS6: J1.2, U1.12
BUS7: J1.1, U1.2, U3.10
CARRY_IN: J5.3, R1.2, U3.6
CARRY_OUT: D8.2, J2.4, J5.1, R14.2
CLK: J3.1, U4.7
C_CTRL: J6.2, R1.1, U5.4
C_D: D4.2, U4.4, U5.13, U6.2
C_I: U3.7, U4.13
GND: C1.2, C2.2, C3.2, C4.2, C5.2, C6.2, C7.2, J4.1, J4.2, R3.1, R4.1, R5.1, R6.1, R10.1, R14.1, R15.1, U1.7, U2.7, U3.8, U3.15, U4.1, U4.2, U4.8, U5.1, U5.2, U5.8, U5.9, U5.10, U6.7
N_CTRL: J6.4, U5.6
N_D: D3.2, U4.6, U5.11, U6.9
N_I: U3.9, U4.11
unnamed: D1.1, R3.2
unnamed: D2.1, R4.2
unnamed: D3.1, R5.2
unnamed: D4.1, R6.2
unnamed: D5.2, R8.2
unnamed: D6.2, R7.2
unnamed: D7.2, R9.2
unnamed: D8.1, R10.2
unnamed: U1.1, U2.2
unnamed: U1.4, U2.1
unnamed: U1.10, U2.13
unnamed: U1.13, U2.12
unnamed: U2.3, U2.5
unnamed: U2.4, U2.11
OV_IN: J5.2, R2.2, U3.3
RST: J3.3, R15.2, U4.15, U5.15
VCC: C1.1, C2.1, C3.1, C4.1, C5.1, C6.1, C7.1, J4.3, J4.4, R7.1, R8.1, R9.1, R11.1, R12.1, R13.1, U1.14, U2.14, U3.16, U4.16, U5.16, U6.14
V_CTRL: J6.1, R2.1, U5.3
V_D: D2.2, U4.3, U5.14, U6.5
V_I: U3.4, U4.14
Z_CTRL: J6.3, U5.5
Z_D: D1.2, U4.5, U5.12, U6.12
Z_I: U3.12, U4.12
Z_OUT: J5.4, U2.6, U3.13
~B_CALC~: D7.1, J2.3, R13.2, U2.9
~B_LOAD~: D5.1, J2.2, R12.2, U2.10, U3.1
~CLK~: J3.2, U5.7
~LATCH~: U2.8, U4.9, U4.10
~OUT~: D6.1, J2.1, R11.2, U6.1, U6.4, U6.10, U6.13

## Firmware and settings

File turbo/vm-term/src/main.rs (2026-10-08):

use std::cell::RefCell;
use std::io::{Read, stdout, Write, stdin};
use termion::input::TermRead;
use termion::raw::IntoRawMode;
use std::rc::Rc;

use turbo_bridge::{CommsChannel, PeekableReceiver};
use turbo_peripherals::Peripherals;
use turbo_core::{Cpu, TrapReason};

enum LocalCommsChannel {
    Debug,
    LCD,
    UART {
        rx: PeekableReceiver<char>,
    },
}

impl LocalCommsChannel {
    pub fn new_uart() -> Self {
        let (tx, rx_c) = std::sync::mpsc::channel();
        let channel = Self::UART {
            rx: PeekableReceiver::new(rx_c),
        };
        channel.start_terminal_reader(tx);
        channel
    }

    fn start_terminal_reader(&self, tx: std::sync::mpsc::Sender<char>) {
        std::thread::spawn(move || {
            let stdin = stdin();
            for key in stdin.keys() {
                if let Ok(k) = key {
                    let chars = match k {
                        termion::event::Key::Up => "\x1b[A",
                        termion::event::Key::Down => "\x1b[B",
                        termion::event::Key::Left => "\x1b[D",
                        termion::event::Key::Right => "\x1b[C",
                        _ => "",
                    };
                    for c in chars.chars() {
                        tx.send(c).expect("Failed to send char to channel");
                    }
                }
            }
        });
    }
}


impl CommsChannel for LocalCommsChannel {
    fn send_response_str(&self, value: &str) {
        stdout().write_all(value.as_bytes()).expect("Failed to write to stdout");
        stdout().flush().expect("Failed to flush stdout");
    }

    fn send_response_byte(&self, value: u8) {
        stdout().write_all(&[value]).expect("Failed to write to stdout");
        stdout().flush().expect("Failed to flush stdout");
    }

    fn send_output_msg(&self, payload: &str, _port: u8) {
        self.send_response_str(payload);
    }

    fn recv_char(&mut self) -> char {
        if let Self::UART { rx, .. } = self {
            rx.recv()
        } else {
            0xFF as char
        }
    }

    fn is_input_available(&mut self) -> bool {
        if let Self::UART { rx, .. } = self {
            rx.peek().is_value()
        } else {
            false
        }
    }
}


fn main() -> std::io::Result<()> {
    // open file specified by command line arguments
    let args: Vec<String> = std::env::args().collect();
    if args.len() < 2 {
        eprintln!("Usage: {} <file>", args[0]);
        std::process::exit(1);
    }
    let filename = &args[1];

    let mut file = std::fs::File::open(filename)?;
    let mut buf = Vec::new();
    file.read_to_end(&mut buf)?;

    let _raw_stdio = stdout().into_raw_mode().ok();

    let comms_channels: Vec<Rc<RefCell<LocalCommsChannel>>> = vec![
        Rc::new(RefCell::new(LocalCommsChannel::Debug)),
        Rc::new(RefCell::new(LocalCommsChannel::LCD)),
        Rc::new(RefCell::new(LocalCommsChannel::new_uart())),
    ];

    let peripherals = Peripherals::new(&comms_channels);
    let mut cpu = Cpu::new(peripherals);

    cpu.write_memory(0, &buf);
    cpu.reset();

    let trap = cpu.run_until_trap();

    match trap {
        TrapReason::Halt => eprintln!("# Halted"),
        TrapReason::Brk => eprintln!("# Break"),
    }

    Ok(())
}

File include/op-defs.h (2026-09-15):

#ifndef OP_DEFS_H
#define OP_DEFS_H

/* Opcodes */
#define OP_NOP                 0x00
#define OP_LDI_A_IMM           0x01
#define OP_LDI_B_IMM           0x02
#define OP_LDI_C_IMM           0x03
#define OP_LDI_D_IMM           0x04
#define OP_LDI_F_IMM           0x05
#define OP_HLT                 0x06
#define OP_ADD_A_A             0x07
#define OP_ADD_A_B             0x08
#define OP_ADD_A_C             0x09
#define OP_ADD_A_D             0x0a
#define OP_ADD_B_A             0x0b
#define OP_ADD_B_B             0x0c
#define OP_ADD_B_C             0x0d
#define OP_ADD_B_D             0x0e
#define OP_ADD_C_A             0x0f
#define OP_ADD_C_B             0x10
#define OP_ADD_C_C             0x11
#define OP_ADD_C_D             0x12
#define OP_ADD_D_A             0x13
#define OP_ADD_D_B             0x14
#define OP_ADD_D_C             0x15
#define OP_ADD_D_D             0x16
#define OP_ADC_A_A             0x17
#define OP_ADC_A_B             0x18
#define OP_ADC_A_C             0x19
#define OP_ADC_A_D             0x1a
#define OP_ADC_B_A             0x1b
#define OP_ADC_B_B             0x1c
#define OP_ADC_B_C             0x1d
#define OP_ADC_B_D             0x1e
#define OP_ADC_C_A             0x1f
#define OP_ADC_C_B             0x20
#define OP_ADC_C_C             0x21
#define OP_ADC_C_D             0x22
#define OP_ADC_D_A             0x23
#define OP_ADC_D_B             0x24
#define OP_ADC_D_C             0x25
#define OP_ADC_D_D             0x26
#define OP_SUB_A_B             0x27
#define OP_SUB_A_C             0x28
#define OP_SUB_A_D             0x29
#define OP_SUB_B_A             0x2a
#define OP_SUB_B_C             0x2b
#define OP_SUB_B_D             0x2c
#define OP_SUB_C_A             0x2d
#define OP_SUB_C_B             0x2e
#define OP_SUB_C_D             0x2f
#define OP_SUB_D_A             0x30
#define OP_SUB_D_B             0x31
#define OP_SUB_D_C             0x32
#define OP_SBB_A_B             0x33
#define OP_SBB_A_C             0x34
#define OP_SBB_A_D             0x35
#define OP_SBB_B_A             0x36
#define OP_SBB_B_C             0x37
#define OP_SBB_B_D             0x38
#define OP_SBB_C_A             0x39
#define OP_SBB_C_B             0x3a
#define OP_SBB_C_D             0x3b
#define OP_SBB_D_A             0x3c
#define OP_SBB_D_B             0x3d
#define OP_SBB_D_C             0x3e
#define OP_AND_A_B             0x3f
#define OP_AND_A_C             0x40
#define OP_AND_A_D             0x41
#define OP_AND_B_A             0x42
#define OP_AND_B_C             0x43
#define OP_AND_B_D             0x44
#define OP_AND_C_A             0x45
#define OP_AND_C_B             0x46
#define OP_AND_C_D             0x47
#define OP_AND_D_A             0x48
#define OP_AND_D_B             0x49
#define OP_AND_D_C             0x4a
#define OP_OR_A_B              0x4b
#define OP_OR_A_C              0x4c
#define OP_OR_A_D              0x4d
#define OP_OR_B_A              0x4e
#define OP_OR_B_C              0x4f
#define OP_OR_B_D              0x50
#define OP_OR_C_A              0x51
#define OP_OR_C_B              0x52
#define OP_OR_C_D              0x53
#define OP_OR_D_A              0x54
#define OP_OR_D_B              0x55
#define OP_OR_D_C              0x56
#define OP_XOR_A_B             0x57
#define OP_XOR_A_C             0x58
#define OP_XOR_A_D             0x59
#define OP_XOR_B_A             0x5a
#define OP_XOR_B_C             0x5b
#define OP_XOR_B_D             0x5c
#define OP_XOR_C_A             0x5d
#define OP_XOR_C_B             0x5e
#define OP_XOR_C_D             0x5f
#define OP_XOR_D_A             0x60
#define OP_XOR_D_B             0x61
#define OP_XOR_D_C             0x62
#define OP_NOT_A               0x63
#define OP_NOT_B               0x64
#define OP_NOT_C               0x65
#define OP_NOT_D               0x66
#define OP_CLR_A               0x67
#define OP_CLR_B               0x68
#define OP_CLR_C               0x69
#define OP_CLR_D               0x6a
#define OP_INC_A               0x6b
#define OP_INC_B               0x6c
#define OP_INC_C               0x6d
#define OP_INC_D               0x6e
#define OP_DEC_A               0x6f
#define OP_DEC_B               0x70
#define OP_DEC_C               0x71
#define OP_DEC_D               0x72
#define OP_SHR_A               0x73
#define OP_SHR_B               0x74
#define OP_SHR_C               0x75
#define OP_SHR_D               0x76
#define OP_ROR_A               0x77
#define OP_ROR_B               0x78
#define OP_ROR_C               0x79
#define OP_ROR_D               0x7a
#define OP_ASR_A               0x7b
#define OP_ASR_B               0x7c
#define OP_ASR_C               0x7d
#define OP_ASR_D               0x7e
#define OP_SWAP_A              0x7f
#define OP_SWAP_B              0x80
#define OP_SWAP_C              0x81
#define OP_SWAP_D              0x82
#define OP_CMP_A_B             0x83
#define OP_CMP_A_C             0x84
#define OP_CMP_A_D             0x85
#define OP_CMP_B_A             0x86
#define OP_CMP_B_C             0x87
#define OP_CMP_B_D             0x88
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

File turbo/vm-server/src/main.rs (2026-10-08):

use turbo_peripherals::Peripherals;
use turbo_bridge::{CommsChannel, UDPCommsChannel};
use std::rc::Rc;
use std::cell::RefCell;

fn main() -> std::io::Result<()> {

    let comms_channels: Vec<Rc<RefCell<UDPCommsChannel>>> = vec![
        Rc::new(RefCell::new(UDPCommsChannel::new(8888))),
        Rc::new(RefCell::new(UDPCommsChannel::new(8889))),
        Rc::new(RefCell::new(UDPCommsChannel::new(8890))),
    ];

    let main_channel = comms_channels[0].clone();

    let peripherals = Peripherals::new(&comms_channels);
    let mut cpu = turbo_core::Cpu::new(peripherals);

    loop {

        let c = main_channel.borrow_mut().recv_char();
        match c {
            'I' => {
                main_channel.borrow().send_response_str("Turbo VM");
            },
            'A' => {
                let addr = main_channel.borrow_mut().recv_int();
                cpu.inject_address_bus_value(addr as u16);
            },
            'a' => {
                let value = cpu.read_address_bus_value();
                main_channel.borrow().send_response_int(value as u32);
            },
            'B' => {
                let value = main_channel.borrow_mut().recv_int();
                cpu.inject_main_bus_value(value as u8);
            },
            'b' => {
                let value = cpu.read_main_bus_value();
                main_channel.borrow().send_response_int(value as u32);
            },
            's' => {
                let value = cpu.read_flags_value();
                main_channel.borrow().send_response_int(value as u32);
            },
            'f' => {
                // is this ever used?
                cpu.clear_injected_values();
            },
            'O' => {
                let _cw = main_channel.borrow_mut().recv_int();
                cpu.clear_injected_values();
                cpu.apply_control_word(turbo_core::DEFAULT_CW);
            },
            'M' => {
                let cw = main_channel.borrow_mut().recv_int();
                cpu.apply_control_word(cw);
            },
            'N' => {
                // NOP
            },
            'c' => {
                cpu.clock_pulse_primary();
            },
            'C' => {
                cpu.clock_pulse_secondary();
            },
            'T' => {
                if let Some(trap) = cpu.clock_tick() {
                    main_channel.borrow().send_response_trap(&trap);
                }
                main_channel.borrow().send_response_str("#T");
            },
            'r' => {
                _ = main_channel.borrow_mut().recv_int(); // client sends control word for IRFetch, discard it
                let value = cpu.read_instruction_register();
                main_channel.borrow().send_response_int(value as u32);
            },
            'R' => {
                let trap = cpu.run_until_trap();
                main_channel.borrow().send_response_trap(&trap);
            },
            'Z' => {
                cpu.reset();
            },
            'W' => {
                let mut channel = main_channel.borrow_mut();
                let cw = channel.recv_int();
                channel.discard_char(); // discard separator
                let mut addr = channel.recv_int();
                channel.discard_char();
                let mut data = channel.recv_int();
                while data < 0x100 {
                    channel.discard_char();
                    cpu.inject_main_bus_value(data as u8);
                    cpu.inject_address_bus_value(addr as u16);
                    cpu.apply_control_word(cw);
                    cpu.clock_tick();
                    addr += 1;
                    data = channel.recv_int();
                }
                channel.send_response_str("#W");
            },
            'Q' => {
                break;
            },
            'E' => {
                let mut channel = main_channel.borrow_mut();
                let chan = channel.recv_int();
                channel.discard_char(); // discard separator
                let port = channel.recv_int();
                drop(channel); // drop immutable borrow to enable set_response_destination to get mutable one
                comms_channels[chan as usize].borrow_mut().set_response_destination(port as u16);
            },
            _ => {
                println!("Received: unknown {}", c);
            }
        }
    }

    Ok(())
}

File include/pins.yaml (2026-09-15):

muxes:
  - name: "OutMux"
    pins:
      - 0
      - 1
      - 2
      - 3
    default: 15
  - name: "LoadMux"
    pins:
      - 4
      - 5
      - 6
      - 7
    default: 15
  - name: "AluArgL"
    pins:
      - 8
      - 9
    default: 0
  - name: "AluArgR"
    pins:
      - 10
      - 11
      - 12
    default: 6
  - name: "AddrOutMux"
    pins:
      - 16
      - 17
      - 18
    default: 7
  - name: "AddrLoadMux"
    pins:
      - 19
      - 20
      - 21
    default: 7
shared_pins:
  - name: "Addr.inc"
    level: "LOW"
    pin: 22
  - name: "Addr.dec"
    level: "LOW"
    pin: 23
  - name: "Memory.out"
    mux: "OutMux"
    pin: 9
  - name: "Alu.carry_in"
    pin: 15
    level: "HIGH"
devices:
  - name: "A"
    type: "GPRegister"
    pins:
      out:
        mux: "OutMux"
        pin: 0
      load:
        mux: "LoadMux"
        pin: 0
      alu_l:
        mux: "AluArgL"
        pin: 0
      alu_r:
        mux: "AluArgR"
        pin: 0
  - name: "B"
    type: "GPRegister"
    pins:
      out:
        mux: "OutMux"
        pin: 1
      load:
        mux: "LoadMux"
        pin: 1
      alu_l:
        mux: "AluArgL"
        pin: 1
      alu_r:
        mux: "AluArgR"
        pin: 1
  - name: "C"
    type: "GPRegister"
    pins:
      out:
        mux: "OutMux"
        pin: 2
      load:
        mux: "LoadMux"
        pin: 2
      alu_l:
        mux: "AluArgL"
        pin: 2
      alu_r:
        mux: "AluArgR"
        pin: 2
  - name: "D"
    type: "GPRegister"
    pins:
      out:
        mux: "OutMux"
        pin: 3
      load:
        mux: "LoadMux"
        pin: 3
      alu_l:
        mux: "AluArgL"
        pin: 3
      alu_r:
        mux: "AluArgR"
        pin: 3
  - name: "AddSub"
    type: "ALU"
    pins:
      out:
        mux: "OutMux"
        pin: 5
      alt:
        level: "HIGH"
        pin: 13
      carry_in:
        pin: "Alu.carry_in"
  - name: "And"
    type: "ALU"
    pins:
      out:
        mux: "OutMux"
        pin: 6
  - name: "Or"
    type: "ALU"
    pins:
      out:
        mux: "OutMux"
        pin: 13
  - name: "Xor"
    type: "ALU"
    pins:
      out:
        mux: "OutMux"
        pin: 10
  - name: "Shift"
    type: "ALU"
    pins:
      out:
        mux: "OutMux"
        pin: 7
      carry_in:
        pin: "Alu.carry_in"
  - name: "Swap"
    type: "ALU"
    pins:
      out:
        mux: "OutMux"
        pin: 14
  - name: "F"
    type: "FlagsRegister"
    pins:
      out:
        mux: "OutMux"
        pin: 4
      load:
        mux: "LoadMux"
        pin: 7
      calc:
        pin: 14
        level: "LOW"
  - name: "Ram"
    type: "RAM"
    pins:
      out:
        pin: "Memory.out"
      write:
        mux: "LoadMux"
        pin: 9
  - name: "ProgMem"
    type: "ROM"
    pins:
      out:
        pin: "Memory.out"
  - name: "T"
    type: "TempRegister"
    pins:
      load:
        mux: "LoadMux"
        pin: 6
      alu_r:
        mux: "AluArgR"
        pin: 4
  - name: "ZeroArg"
    type: "ConstArg"
    pins:
      alu_r:
        mux: "AluArgR"
        pin: 6
  - name: "OnesArg"
    type: "ConstArg"
    pins:
      alu_r:
        mux: "AluArgR"
        pin: 5
  - name: "IR"
    type: "WORegister"
    pins:
      load:
        mux: "LoadMux"
        pin: 8
  - name: "Clock"
    type: "Clock"
    pins:
      halt:
        pin: 26
        level: "LOW"
      brk:
        pin: 27
        level: "HIGH"
  - name: "StepCounter"
    type: "StepCounter"
    pins:
      reset:
        pin: 24
        level: "LOW"
      extended:
        pin: 25
        level: "LOW"
  - name: "PC"
    type: "ProgramCounter"
    pins:
      out:
        mux: "AddrOutMux"
        pin: 5
      load:
        mux: "AddrLoadMux"
        pin: 5
      inc:
        pin: "Addr.inc"
  - name: "TX"
    type: "TransferRegister"
    pins:
      out:
        mux: "AddrOutMux"
        pin: 0
      load:
        mux: "AddrLoadMux"
        pin: 0
  - name: "TH"
    type: "TransferRegister"
    pins:
      out:
        mux: "OutMux"
        pin: 12
      load:
        mux: "LoadMux"
        pin: 12
  - name: "TL"
    type: "TransferRegister"
    pins:
      out:
        mux: "OutMux"
        pin: 11
      load:
        mux: "LoadMux"
        pin: 11
  - name: "SP"
    type: "StackPointer"
    pins:
      out:
        mux: "AddrOutMux"
        pin: 3
      load:
        mux: "AddrLoadMux"
        pin: 3
      inc:
        pin: "Addr.inc"
      dec:
        pin: "Addr.dec"
  - name: "SDP"
    type: "StackPointer"
    pins:
      out:
        mux: "AddrOutMux"
        pin: 1
      load:
        mux: "AddrLoadMux"
        pin: 1
      inc:
        pin: "Addr.inc"
      dec:
        pin: "Addr.dec"
  - name: "TDP"
    type: "StackPointer"
    pins:
      out:
        mux: "AddrOutMux"
        pin: 6
      load:
        mux: "AddrLoadMux"
        pin: 6
      inc:
        pin: "Addr.inc"
      dec:
        pin: "Addr.dec"
  - name: "LR"
    type: "AddressRegister"
    pins:
      out:
        mux: "AddrOutMux"
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

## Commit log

2021-02-07 Filter out aliased pins
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2021-02-13 Add fuses command for Bouncyy
2021-02-22 Corrected adder footprints on AUnit, needs re-routing
    [aunit.kicad_pcb, aunit.sch]
2021-02-22 Rerouted for new footprints (checkpoint)
    [aunit.kicad_pcb]
2021-02-22 Power and ground plane optimizations
    [aunit.kicad_pcb]
2021-02-25 Corrected footprints for Flags, needs re-routing
    [flags.kicad_pcb, flags.sch]
2021-02-25 Quick and ugly reroute (checkpoint)
    [flags.kicad_pcb]
2021-02-25 Carry pass-through
    [flags.sch]
2021-02-25 Swap selector input
    [flags.sch]
2021-02-25 Rewire control signals to BLOAD, BCALC
    [flags.sch]
2021-02-27 Removed all tracks
    [flags.kicad_pcb, flags.sch]
2021-02-27 Moved around for easier routing
    [flags.kicad_pcb, flags.sch]
2021-02-27 Import autorouted
    [flags.kicad_pcb]
2021-02-27 Connected (checkpoint)
    [flags.kicad_pcb]
2021-02-27 Flags 2.0 finalized
    [flags.kicad_pcb, flags.sch]
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2021-03-13 Preliminary schematics for Control Unit
    [control.kicad_pcb, control.sch]
2021-03-22 Remove all tracks
    [aunit.kicad_pcb]
2021-03-22 Swap gates and add missing caps
    [aunit.sch]
2021-03-22 Move stuff around
    [aunit.kicad_pcb]
2021-03-22 Routed AUnit on 4-layer
    [aunit.kicad_pcb]
2021-03-22 Clean tracks again
    [flags.kicad_pcb]
2021-03-22 Rerouted Flags as 4-layer
    [flags.kicad_pcb]
2021-04-04 Schematics for RAM
    [ram.kicad_pcb, ram.sch]
2021-04-11 ALU backplane parts + board
    [alu_back.kicad_pcb, alu_back.sch]
2021-04-11 Board routing and fills
    [alu_back.kicad_pcb]
2021-04-11 Flags board
    [alu_back.kicad_pcb, alu_back.sch]
2021-04-12 Add some connectors
    [alu_back.kicad_pcb, alu_back.sch]
2021-04-12 Add connectors for control wires
    [alu_back.sch]
2021-04-13 Switch to 24-bit control word
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2021-04-14 Rename ALU function pin
2021-04-14 Fix pin assignment - same pin for all ALU Alt
2021-04-17 Re-select microcode "threads" on each step
2021-04-18 Add LR and PCSw devices
2021-04-25 ALU backplane board
    [alu_back.kicad_pcb, alu_back.sch]
2021-04-25 Backplane finishing touches
    [alu_back.kicad_pcb, alu_back.sch]
2021-04-25 Gerber settings for board production
    [alu_back.kicad_pcb, aunit.kicad_pcb, flags.kicad_pcb]
2021-04-29 Print nonzero - simple program for "dissection"
2021-05-11 Adjust ALU input controls for PCB version
2021-05-11 Switch to 32-bit control word
2021-05-11 Move HAS.out to individual pin
2021-05-12 Switch the rest of Stack tests to cpu_helper
2021-05-13 Char Out device and instructions
2021-05-13 Print Hello World using cout
2021-05-15 Prepare Logic Unit board - cleaned copy from Arithmetic Unit
    [lunit.kicad_pcb, lunit.sch]
2021-05-15 Add And/Or/Sel chips
    [lunit.kicad_pcb, lunit.sch]
2021-05-15 Add Sx65 Display part and footprint
2021-05-16 Place the chips
    [lunit.kicad_pcb, lunit.sch]
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2021-06-08 Routed function part
    [lunit.kicad_pcb, lunit.sch]
2021-06-09 Route the rest
    [lunit.kicad_pcb, lunit.sch]
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2021-06-10 Preliminary board layout of Diplay backend board
    [display_back.kicad_pcb, display_back.sch]
2021-06-13 Display backend - schematics and board
    [display_back.kicad_pcb, display_back.sch]
2021-06-13 Parts silk and values
    [display_back.kicad_pcb, display_back.sch]
2021-06-15 Remove MAR, HAS - switch to dedicated address_bus
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2021-06-16 Change PC/LR to fixed devices
2021-06-21 Display front template board
    [display_front.kicad_pcb, display_front.sch]
2021-06-21 Display front schematics
    [display_front.kicad_pcb, display_front.sch]
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2021-07-04 Add silk for front
    [display_front.kicad_pcb, display_front.sch]
2021-07-04 Finishing touches
    [display_back.kicad_pcb, display_back.sch]
2021-07-04 Improve ground plane
    [display_front.kicad_pcb, display_front.sch]
2021-07-04 Fix ALU input selector
    [alu_back.kicad_pcb, alu_back.sch]
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2021-07-05 Re-map ALU R arg to match bodge-fixed backplane
    [op-defs.h]
2021-07-07 Reorganize so that opcode could be switched mid-flight
2021-07-10 Clean up explicit ram hooking, depends on state of Immediate pseudo-device now
2021-07-18 Transfer register
    [transfer.kicad_pcb, transfer.sch]
2021-07-21 Q-Clock breadboard and updated simulation
    [q-clock-v2.fz]
2021-07-22 Flash writer - Arduino Shield
    [flash_writer.kicad_pcb, flash_writer.sch]
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2021-07-22 Add CE control
    [flash_writer.kicad_pcb, flash_writer.sch]
2021-07-23 Program Counter board
    [counter.kicad_pcb, counter.sch]
2021-07-25 PC finishing touches
    [counter.kicad_pcb, counter.sch]
2021-07-25 Writer finishing touches
    [flash_writer.kicad_pcb, flash_writer.sch]
2021-07-25 Plot settings
    [counter.kicad_pcb, display_back.kicad_pcb, display_front.kicad_pcb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]
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2021-09-06 Shift Unit - schematics and preliminary placement
    [sunit.kicad_pcb, sunit.sch]
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2021-10-16 Switch ALU to pins variant of chips where appropiate
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2021-12-28 Replace Verilator runner with VPI plugin
    [main.cpp]
2021-12-28 Remove verbose print, fix read_current_opcode handler
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2022-01-16 Remove dependencies from Arduino libs and port Flash ops to C
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2022-01-20 Move former EEPROM burner code to Misc. utilities
    [op-defs.h]
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2022-02-02 Swap places for hlt and lea instructions
    Need low-number opcode for HLT
    [op-defs.h]
2022-02-02 Implement HLT by stalling StepCounter
    [op-defs.h]
2022-02-06 Revert "Implement HLT by stalling StepCounter"
    This reverts commit 59f4c81eee55d15dc6d49b39fbc95e1c6df6952f.
    [op-defs.h]
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2022-05-04 Rework I/O using IOCtl device
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2023-11-12 Reworked pin-sharing
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2024-08-20 Replace PC & LR with SP board
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2025-10-08 Port direct ALU access to pre-selected device members
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2025-10-08 Port direct Flags access to pre-selected device members
2025-10-08 Port direct RAM and ProgMem access to pre-selected device members
2025-10-08 Port direct IR, Clock and StepCounter access to pre-selected device members
2025-10-08 Port direct PC access to pre-selected device members
2025-10-08 Port direct LR, T*, ACalc and IOCtl access to pre-selected device members
2025-10-09 Port direct gp reg access to pre-selected device members
2025-10-09 Port direct address reg access to pre-selected device members
2025-10-09 Re-export the devices for shorter access
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2025-10-24 Extract pin resolver
2025-10-24 Refactor pin resolver
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2025-10-24 Adjust pin duplicate filter - fix tests
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2026-05-29 Prevent UART read when it is not selected
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2026-07-18 Fix main bus inject and clearing values lacking source
    [main.rs]
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2026-08-12 Tick protocol redesign - optional RunMessage as answer
    [main.rs]
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2026-09-15 Split ShiftSwap into Shift and Swap
    [op-defs.h, pins.yaml]
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
